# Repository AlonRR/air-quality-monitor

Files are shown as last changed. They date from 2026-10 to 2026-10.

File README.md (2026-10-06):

# Air-quality monitor

An ESPHome air-quality monitor — particles with a Sensirion SPS30, VOC and NOx with a GY-SGP41, on an
ESP32-C3 SuperMini — and the printed box it lives in. It watches the air wherever something puts particles
or gases into it: 3D printing, soldering, laser cutting, resin work, sanding, cooking. Its first job is
beside a 3D printer's enclosure, and that is where the design pages measure it, but nothing in the box
assumes a printer.

The box hangs on a wall by two screws, upright, with the SPS30's air face down. Two parts in ASA,
68.7 × 76.4 × 24 mm: a back plate, and a cover whose top locates on a bump in a U and whose bottom corners
are screwed into nuts, the screws' heads flush in its front.

The SuperMini lies level above the SPS30's lead, held by its edges, its antenna's pole standing up; the
SGP41 lies flat in the column beside the SPS30, close behind vents in the cover's front.

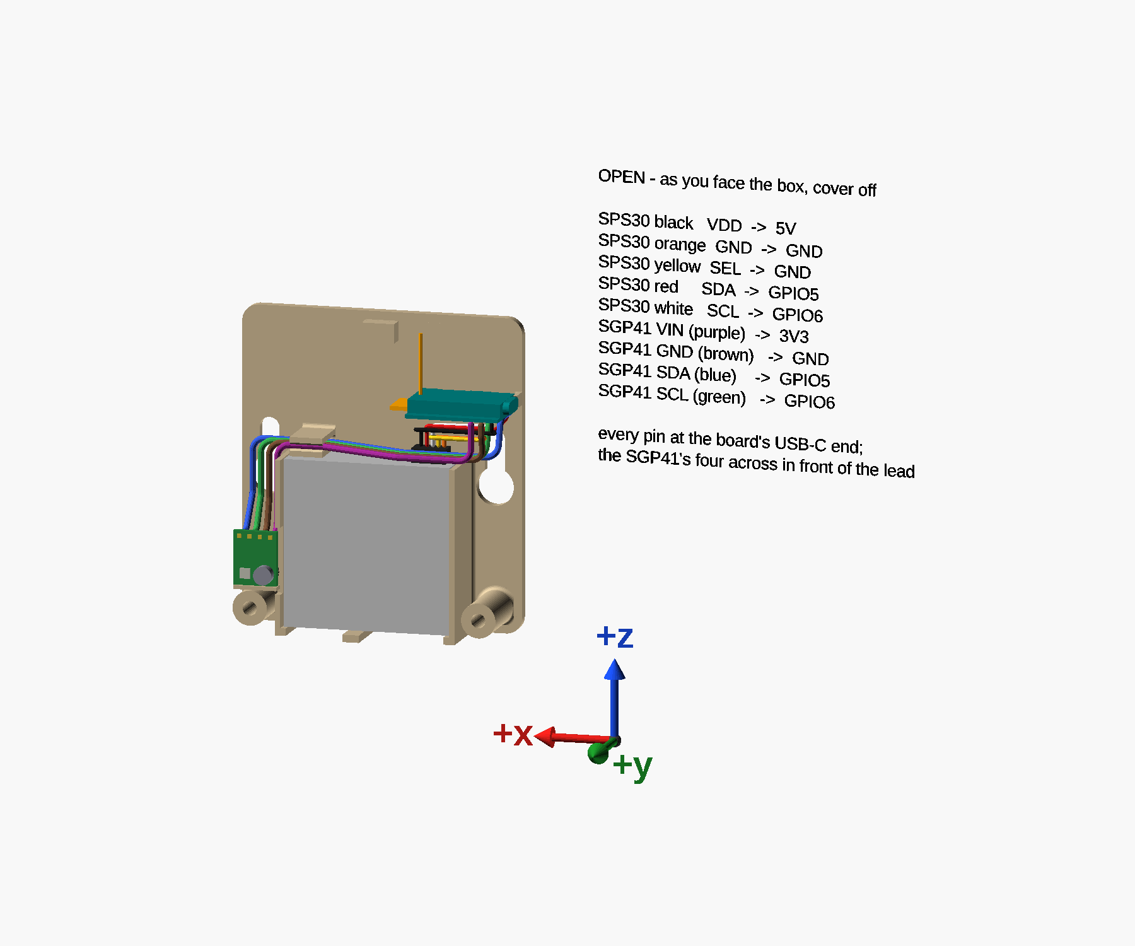
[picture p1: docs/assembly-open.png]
assembled, cover off


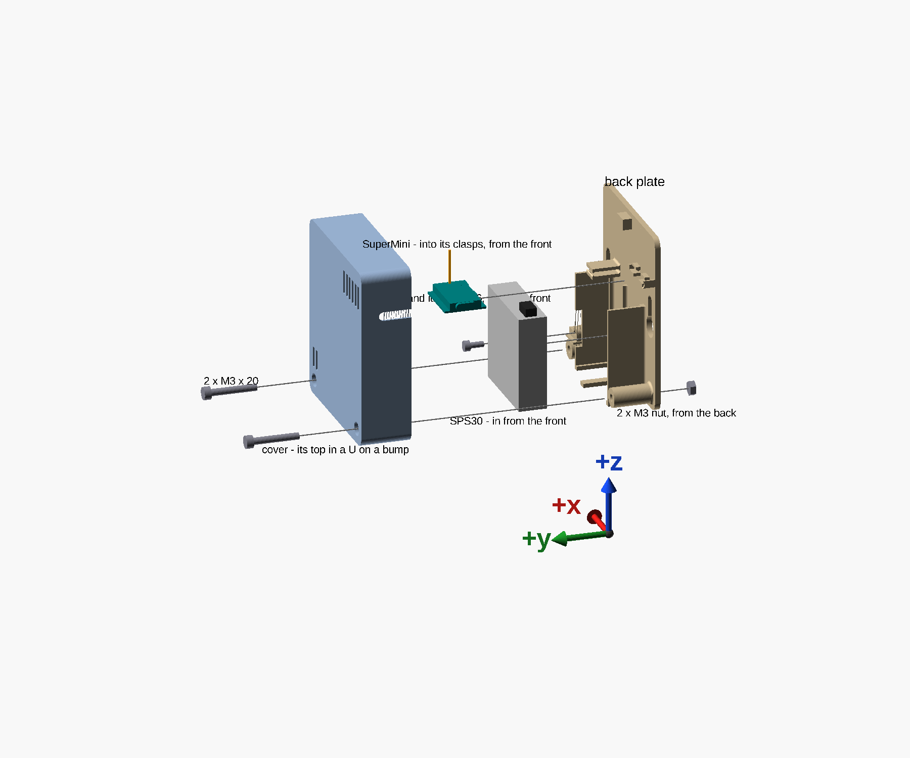
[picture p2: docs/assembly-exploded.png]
every part, moved apart along the way it goes in


Every picture carries the box's own axes as arrows: **x across it, y out from the wall, z up.** Facing the
box, +x points to your left. They are the model's axes, not the printer's: the back plate prints lying on
its back, so on the bed its y is up.

## Status

**The box is modelled, checked, and every fit in it tested** in ASA on the printer; `untested_fits` and
`unmeasured` are both empty, so `scad-check.sh` passes the back plate and the cover.

**Changed since the last printed box** — checked in the model, not printed yet:

- the USB-C slot in the cover's side wall, open to its back edge;
- the divider under the SPS30: a flush wall, placed at the air-face gap measured on the sensor;
- the SGP41 wire channel's lips, now one bead deep;
- the SPS30 standing 2 mm off the plate on three ribs, so air rises behind it and cools it;
- 1 mm fillets at the roots of the thin parts that take a load, and round the SPS30's window.

**The firmware's** configuration is valid and has compiled; it is not flashed yet.

## Building it

1. **Print the two parts** — see *Printing* below.
2. **[Assemble it](docs/assembly.md)**, then **[wire it](docs/wiring.md)**.
3. **Flash the firmware**: copy `firmware/secrets.yaml.example` to `firmware/secrets.yaml`, which is
   gitignored, fill it in, and build [`firmware/print-chamber.yaml`](firmware/print-chamber.yaml) — its
   header says how.

| Part | File | Prints |
|---|---|---|
| Back plate | [`models/air-quality-monitor-back.scad`](models/air-quality-monitor-back.scad) | flat on its back |
| Cover | [`models/air-quality-monitor-cover.scad`](models/air-quality-monitor-cover.scad) | front face down |

**The models need the [`scad-tools`](https://github.com/AlonRR/scad-tools) submodule**, which holds the
shapes they use. Clone with it:

```sh
git clone --recursive https://github.com/AlonRR/air-quality-monitor
```

A ZIP from GitHub comes without it: from the unpacked folder, fetch the version this repository is pinned
to. In PowerShell:

```powershell
$pin = (Invoke-RestMethod https://api.github.com/repos/AlonRR/air-quality-monitor/contents/scad-tools).sha
Invoke-WebRequest "https://github.com/AlonRR/scad-tools/archive/$pin.zip" -OutFile scad-tools.zip
Remove-Item -Recurse -ErrorAction SilentlyContinue scad-tools
Expand-Archive scad-tools.zip . ; Rename-Item "scad-tools-$pin" scad-tools ; Remove-Item scad-tools.zip
```

or in a POSIX shell:

```sh
pin=$(curl -s https://api.github.com/repos/AlonRR/air-quality-monitor/contents/scad-tools | sed -n 's/.*"sha": *"\([0-9a-f]*\)".*/\1/p')
rm -rf scad-tools && mkdir scad-tools && curl -sL "https://github.com/AlonRR/scad-tools/archive/$pin.tar.gz" | tar xz --strip-components=1 -C scad-tools
```

**Hardware:** two M3 × 20 socket head cap screws and two M3 nuts for the cover, one M2.5 × 6 socket head cap
screw for the SGP41, two 4 × 20 chipboard screws and their wall plugs to hang it, and half a metre of
22 AWG solid hookup wire for the SGP41 — [how much each wire takes](docs/wiring.md#how-much-wire). No
tape, no glue.

## Printing

Inslogic ASA, with the print profile **"0.2mm QUALITY @MK3 - no skirt, no brim, no crossing perimeter"**.
No skirt, no brim, no draft shield, and no supports: rounded corners keep ASA's corners down, and every
opening is a hole in the first layers or a notch open at an edge.

## How it is designed

| Page | What it covers |
|---|---|
| [Design](docs/design.md) | the rules the SPS30 sets, the layout they produce, and which way is left |
| [What each feature is for](docs/features.md) | both parts, every feature numbered |
| [The USB-C end](docs/usb-c-end.md) | why any cable fits, and what takes a plug's push and pull |
| [The SGP41's mount](docs/sgp41-mount.md) | how the gas sensor sits close to its vents without loading its parts |
| [Parameters](docs/parameters.md) | every measured, sourced and tested value, and where it came from |
| [Checking it](docs/checking.md) | the checks that guard the design, and the controls that prove each can fail |

## What is where

| | |
|---|---|
| [`docs/`](docs/) | the pages above and their pictures |
| [`models/air-quality-monitor.params.scad`](models/air-quality-monitor.params.scad) | every setting, measurement and fit — the one file to edit |
| [`models/air-quality-monitor.layout.scad`](models/air-quality-monitor.layout.scad) | every dimension the settings imply, and the rules (asserts) they must keep — values only, no geometry |
| [`models/air-quality-monitor.scad`](models/air-quality-monitor.scad) | the model: both parts drawn from the layout, and its collision checks |
| `models/air-quality-monitor-back.scad`, `-cover.scad` | one part each; check and slice through these |
| [`models/assembly-views.scad`](models/assembly-views.scad) | the assembly pictures: exploded; open, with every wire's route and the wiring table; the wires at the pins close up; and the wires' collision check |
| [`models/feature-map.scad`](models/feature-map.scad) | the numbered feature pictures |
| [`models/board-measure.scad`](models/board-measure.scad) | the readings taken on the SuperMini and the GY-SGP41 |
| [`firmware/`](firmware/) | the node's ESPHome configuration, with its wiring table, and the secrets template. It is `print-chamber.yaml`, named for its first job: Home Assistant keys the history it records to that name |
| [`scripts/checks.py`](scripts/checks.py) | the collision checks, the positive controls and the pictures, run as [Checking it](docs/checking.md) describes |
| [`scad-project.toml`](scad-project.toml) | what the shared scripts need to know about this repository: its printed parts |
| [`scad-tools/`](https://github.com/AlonRR/scad-tools) | the shared tools, a git submodule: the xyz arrows, shapes and wire routes the models `use`; `scad-check.sh`; `printables.py`, which makes each printed part one `.scad` and its STL for Printables - `uv run scad-tools/scripts/printables.py`, into `printables/` |

## Licence

This is open hardware. **Commercial use is allowed**, but anyone who ships a product made from these designs
must publish their changes under the same licence.

| Licence | Covers |
|---|---|
| [CERN-OHL-S-2.0](LICENSES/CERN-OHL-S-2.0.txt) — CERN Open Hardware Licence v2, Strongly Reciprocal | the design and its documentation: `models/`, `docs/` and this README |
| [MPL-2.0](LICENSES/MPL-2.0.txt) — Mozilla Public License 2.0 | the code: `firmware/` and `scripts/` |

Every file says which licence applies to it. The `.scad` files, the script and the firmware carry an SPDX
header; `REUSE.toml` covers the rest, and the repository passes `reuse lint`. `LICENSE` at the root is
the CERN-OHL-S text again, for tools that look only there.

## Related

This repository was split out of the [3D-printing toolkit](https://github.com/AlonRR/3d-printing-toolkit),
with its history. The toolkit holds the FDM design rules and the slicer profiles the box is printed with;
the chamber-sensor notes the firmware follows, and the `.yaml` files its comments name, are in
[**printer-enclosure**](https://github.com/AlonRR/printer-enclosure), the enclosure this monitor hangs
beside. A `docs/…` page named in a comment, and not found here, is in one of the two.

_Parts of this repository were drafted with the help of an LLM agent; reviewed and verified locally._

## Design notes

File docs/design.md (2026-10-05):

# Design — why the box looks like this

Most of the layout is decided by the SPS30, and Sensirion publishes the rules. Three more come from
this repository. This page lists them, then shows the layout they add up to.

## The rules

| Rule | Source |
|---|---|
| **Two inlets and one outlet, all on one 40.6 × 12.2 mm face.** The large slotted grille is the **outlet**; the two inlets sit at the other end, one of them wrapping round the edge | *Mechanical Design and Assembly Guidelines for SPS30*, §1 figure |
| **Couple that face to the room through a large opening, with minimal depth in front of it.** A constricted volume in front makes outlet air flow back into the inlets | guidelines §2.1 |
| **A tight seal between the inlet side and the outlet side** gives the best performance | guidelines §2.1 |
| **Openings facing down** is the best orientation — it avoids dust settling in the sensor | guidelines §2.2 |
| **Keep it away from heat sources such as microcontrollers, and below them** — convection from a warm board heats the sensor | guidelines §2.4 |
| **Do not cover the entire sensor surface** in an all-round casing, or it overheats | guidelines §3 |
| **Isolate it from airflow faster than 1 m/s** — so not in the fume fan's stream | guidelines §2.3 |
| **The metal housing is tied to GND and must stay electrically floating**; current through that link *"may damage the product and poses a safety risk through overheating"* | datasheet v2.0 §3 |
| **Connector on the face opposite the openings** | datasheet v2.0 §3 |
| **I2C lead under 20 cm** | datasheet v2.0 §3 |

From this repository:

- **The box sits outside the printer's enclosure.** The SGP41 is rated −10 to +50 °C and the SPS30 to
  +60 °C, against a chamber wanted at 40–60 °C ([chamber-sensor §3](https://github.com/AlonRR/printer-enclosure/blob/main/docs/chamber-sensor/node-design.md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)).
  What those ratings mean is below.
- **A second box inside the chamber is possible, not decided** (Alon, 3 Oct 2026). There are two of
  each sensor, and it would pair with the chamber's air filter — measuring the chamber air out of the
  filter's draught, not built into its air path. Alon does not want to risk the sensors, so it waits
  on more thinking; this box, outside, is built first.
- **The SuperMini carries a 31 mm antenna-wire mod**, whose last 15 mm stand straight up from the
  board ([chamber-sensor §3x](https://github.com/AlonRR/printer-enclosure/blob/main/docs/chamber-sensor/supermini-antenna.md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)). It needs free space in plastic, away
  from the SPS30's grounded metal case.

### Past the ratings

From the datasheets — the SGP41's §2.3–2.4 and the SPS30's (v2.0) §1.2 and §2.2. Neither part stops at
its limit: past it, accuracy goes first, then the part.

| | Performs best | Rated to | Past that |
|---|---|---|---|
| **SGP41** | −10 to 50 °C. Prolonged exposure outside it *"may reduce sensor performance"* | 55 °C, the absolute operating maximum | beyond 55 °C, *"may cause permanent damage"*; long periods at the limits *"may affect sensor performance and reliability"* |
| **SPS30** | 10 to 40 °C | 60 °C, the absolute operating maximum | beyond 60 °C, permanent damage is possible and operation is not guaranteed. The datasheet names a laser failure at very high temperatures, which the sensor flags in its status register. Its precision also drifts by typically 0.5 % of the reading per °C away from 25 °C |

Against the closed chamber — 45–46 °C through an ASA print, 47.5 °C at the peak of a bed anneal
([measurements](https://github.com/AlonRR/printer-enclosure/blob/main/docs/chamber-sensor/measurements.md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)) —
the SPS30 is already above its best range, and the SGP41 is 2.5–5 °C below its 50 °C, before the box's
own heat, which is not measured. Heating the chamber towards 60 °C would take both past their ratings.

## The layout

Every rule points the same way. Stand the SPS30 on edge with its air face **down**, over a window in the
bottom wall; its connector is then **up**, at the outlet end. Lay the SuperMini **level above it**, just
over the lead, so the board's heat rises away from the sensor and its antenna's pole stands up into the
top of the box, away from the sensor's grounded case. Lay the SGP41 flat **beside** the SPS30, its
sensor about 2 mm behind vents in the cover's front.

assembled, cover off

As you face the box, cover off:

- **The SPS30** stands at the bottom centre, in a channel on the back plate, label towards you, its outlet
  on your right. A divider under its air face splits the inlet side from the outlet side.
- **The SuperMini** lies level across your right half, 54.8 mm up, component side up. Its USB-C end is in
  the right-hand wall; its antenna end points to the middle, and the antenna's pole stands 1 mm short of
  the top wall. It is held by its long edges — two clips on the plate take its back edge and a clasp on
  the cover its front edge — so the pins along both stay open from below.
- **The SGP41** lies flat low in the left-hand column, its sensor towards vents in the cover's front and
  its pins up, screwed from the front onto a post rising from the plate.
- **Two keyholes**, one in each side column beside the SPS30's top corners, hang the box on two wall
  screws.
- **The cover** locates at the top on a bump inside a U, and two M3 screws through its bottom corners,
  their heads flush, close it into nuts in the back plate.

**One large window, one divider.** The window is a single opening over the whole air face, split by a
single divider. The box does not have to line up with each grille; it only has to put the divider in
the blank gap between the two ends, which is one number to measure. The divider fills that gap, 4.05 mm
wide and 0.55 mm clear of the openings either side, and ends flush with the box's bottom edge — Sensirion's
own separating wall reaches the device's opening and stops there. It can be no wider: on the inlet side
the gap ends at the slot along the label face's edge, which is the sensor's second inlet.

**The SPS30 stands 2 mm off the plate, for cooling** (`sps_lift`). Three upright ribs hold its back off:
one at each end, against the channel's walls, and one behind the divider. Air comes in through the window
under the sensor, rises up the gap behind it and leaves into the compartment above, past the board and out
through the board's vents. The middle rib splits that gap the way the divider splits the window, so the
outlet's air rising behind the sensor stays on its own side until it is past the sensor's top. The box's depth is set by the
SuperMini's width, not the sensor, so the lift costs only air gap in front of the sensor — 5.6 mm is left,
against `front_gap_min`'s 2.5. What limits it is the sensor's plug, which moves forward with it: the
SGP41's wires pass just in front of the plug, and 2 mm leaves them 0.55 mm clear, where 3 mm ran into them. The SGP41 overhangs only the channel's wall beside it, never the sensor, so
the wall's notch for it may now reach past the sensor's back half: it still guides more than half the
sensor's depth there, and the full depth elsewhere.

**Every pin the node uses is among the first three at the board's USB-C end** — 5V, GND and 3V3 on its
front edge, GPIO5 and GPIO6 on its back edge. So the clips start past the back edge's second pin and the
clasp past the front edge's third, and nothing printed covers a pin that is soldered.

What each feature is for is in [Features](features.md); the SGP41's mount in
[The SGP41's mount](sgp41-mount.md); the USB-C end in [The USB-C end](usb-c-end.md).

## Left and right

**"Left" and "right" always mean as you face the box.** The model's frame is right-handed with Y
pointing out of the wall, so +X is your **left**. The layout above is for the SPS30 in hand, whose outlet
is on your right (`outlet_at_left = false`), so the USB-C cable leaves on your right too.

The model can mirror for a sensor the other way round. A real GY-SGP41 cannot be mirrored, so when the
box is, the model draws the module's mirror image first and it comes out the right way round.

## Printing without support

**The back plate prints on its back.** The keyholes are openings in its first layers. The channel
walls, clips, stop, the SGP41's post, rib and ledge, the bump and the wire channel's ribs are walls
standing on it; the wire channel's lips are 45° ledges at the ribs' tops, and the SGP41's pilot is an
upright hole down its post. The nut pockets open on the bed side, and each pocket's ceiling is bridged in
three layers — a slot the screw hole's width, then a square, then the round hole — so it needs no
support. Nothing overhangs: the SGP41 was first held on edge by a peg standing 2.7 mm sideways out of a
block, and that peg did not print, which is why it now lies flat.

**The cover prints front face down.** The window under the SPS30 is a notch open at the back edge, and
the vents in the front are holes in its first layers. The counterbores the screw heads sit in open on the
bed, and their floors are bridged the same three-layer way as the nut pockets. The partition, baffle,
clasp, stop and U are walls standing on the front. The USB-C slot in the right-hand wall is open at the
cover's back edge — its top on the bed — so it needs no bridge at all.

**No skirt, no brim, no draft shield.** Rounded corners in plan view (`corner_r`) keep ASA's corners
down instead.

## Fillets at the thin parts' roots

**For strength, a concave fillet runs along the root of each thin part**, where it meets the face it stands
on — `fillet_r`, 1 mm, about two beads, so a 0.9–1.35 mm part is roughly twice as thick where it bends.
Only in 90° inside corners; outside edges stay as they are. On the back plate: the SPS30 channel's walls,
the divider, the wire channel's ribs, the USB-C filler, the nut bosses, the back stop and the SGP41's
ledge. On the cover: the partition, the U's arms, the front stop, and all round the inside where the walls
meet the front — the walls already meet each other in a radius.

**Round the window under the SPS30, every corner is filleted, for looks**: the window's two front
corners on the cover, and through it on the plate the divider, the ledges and the standoff ribs where they
meet the plate. The inside cove stops at the window, where there is no bottom wall for the front to meet.

**The board's clips and the cover's clasp have none, on purpose.** They hold the board by flexing, and their
fit was set by printing them; a fillet would stiffen them, change how the board snaps in, and make them
likelier to crack than to give. The baffle, the SGP41's post and rib see almost no load, so they have none
either.

**Some corners stay sharp because something fits against them**, and those are deliberate: the channel
walls' inner faces, which the SPS30 stands 0.355 mm off; the lower wire rib's underside, `part_fit` over the
sensor; the USB-C filler's outside face and its edges in the cover's slot; the divider's top, which carries
the sensor; the stops' faces the board bears on. Each fillet is cut back `fillet_clear` (`part_fit`) from
the cover's walls, the plate's bump and the cover's bottom wall, and the cover's window, thinned USB-C wall
and vents cut through the inside one. [Checking it](checking.md) has the setting that proves those
cut-backs are there.

**No fillet makes an overhang.** The back plate's widen down towards its bed, the cover's towards its front,
which is its bed, and the fillets under the cover's top wall run straight up it.

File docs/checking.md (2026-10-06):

# Checking it

How to tell that the model is still right after a change. There are two layers: the repo's
`scad-check.sh` on each printed part, and five collision checks in the model, backed by its asserts.
The wire routes and their checks are on [Wiring](wiring.md).

Everything below except `scad-check.sh` runs from one script, with OpenSCAD 2021.01 and
[uv](https://docs.astral.sh/uv/), from the repository's root:

```sh
uv run scripts/checks.py collisions   # the five collision checks, the box both ways round; and check_wires
uv run scripts/checks.py controls     # every positive control below and on Wiring, re-measured
uv run scripts/checks.py figures      # every picture in docs/, each render read for errors
uv run scripts/checks.py lengths      # the wire lengths on Wiring, against the routes they come from
```

Each exits 1 if anything is not as this page says. `JOBS=4` runs four renders at once. `figures` renders
into a scratch folder; `figures --write` renders over the pictures in `docs/`. Rendering the same model
twice gives PNGs a few hundred bytes apart, so write and commit them only when the model changed.

Every check here has a **positive control**: a setting that breaks the thing being checked, with what it
measured. A check that has never been seen to fail is not yet evidence. If a control stops failing after
a change, the check has gone blind and needs a new control.

## Each printed part — `scad-check.sh`

Run from the repository's root:

```sh
P="0.2mm QUALITY @MK3 - no skirt, no brim, no crossing perimeter"
scad-tools/scripts/scad-check.sh models/air-quality-monitor-back.scad  "$P" "Inslogic ASA"
scad-tools/scripts/scad-check.sh models/air-quality-monitor-cover.scad "$P" "Inslogic ASA"
scad-tools/scripts/scad-check.sh models/fits/air-quality-monitor-fits.scad  "$P" "Inslogic ASA"
```

Each should report **one manifold part** and `fdm_*` values matching the profile: the back plate and the
cover each 68.7 × 76.3 mm on the bed.

- **Exit 2 is expected** for the back plate and the cover while `untested_fits` or `unmeasured` is not
  empty; exit 0 means both are clear, as they both are now. The clearance test reports neither, so
  it exits 0.
- `scad-check.sh` also fails a G-code with a skirt or a brim. The profile above has neither.
- **Always check through the three wrapper files, never through `air-quality-monitor.scad` itself.** The
  `part` line in the params file is also what you change to look at a part, and `scad-check.sh` takes no
  `-D`, so a check through the model silently checks whichever part is on screen.

## Collisions — in the model

`checks.py collisions` renders each to STL; by hand, from the repository's root:

```sh
openscad -o check.stl -D 'part="check_components"' models/air-quality-monitor.scad
```

**Run each with `outlet_at_left` set both ways** (add `-D outlet_at_left=true`). The model mirrors, and a
check run one way only has passed a mirrored mistake before. `check_parts` touches by design, so CGAL warns
that its zero-volume result is not a valid 2-manifold; that warning is expected there.

| Check | What it intersects | Must be |
|---|---|---|
| `check_parts` | the back plate with the cover | **zero volume** — they meet only where they touch: the cover's back edge on the plate, and the nut bosses' ends on the cover's screw bosses |
| `check_components` | both parts with everything inside: the SPS30; the SuperMini's PCB (less the clips' pinch, which is meant), its parts, USB-C shell, antenna loop and pole; the largest compliant plug's body, seated, with the board pushed against its stops; the column the SPS30's lead rises through; the SGP41 lying flat, less the bare strip and the bare ring round its hole where it bears; its screw's head; and the wall screws' heads behind the plate, all the way from entry to hung | **empty** |
| `check_slide` | the back plate with the SuperMini's way in: each of its pieces swept from in front of the box into its clips | **empty** |
| `check_insert` | the back plate with the SPS30's way in: its outline, nubs included, swept from its seat to the cover's front | **empty** |
| `check_cover_on` | the cover with its way on: everything inside the box — the SPS30, the SuperMini piece by piece, the SGP41 and its screw's head — swept back to the plate, the way each moves against the cover as the cover comes on | **empty** |

"Empty" means OpenSCAD writes no file; "zero volume" means the STL it writes has none.

## Positive controls

Each setting breaks one thing; the check, or an assert, must catch it. Measured 5 Oct 2026.

`checks.py controls` reads both tables from this page, and the wire routes' table from
[Wiring](wiring.md), and runs every row. It fails a control that no longer fails (**blind**: its check can no longer see what it guards) and one that fails by a different
amount than the table gives (**moved**: the geometry changed, so this page is out of date).

| Check | Setting | What it breaks | Measured |
|---|---|---|---|
| `check_parts` | `part_fit = -0.6` | the cover's features overlap the plate's | 237.9 mm³ |
| `check_parts` | `bump_z1 = 75` | the bump at the top into the cover's top wall | 14.4 mm³ |
| `check_parts` | `nut_boss_y1 = 21.5` | the nut bosses run into the cover's screw bosses | 190.5 mm³ |
| `check_components` | `z_f0 = 50` | the board lowered into the column the SPS30's lead rises through | 8.8 mm³ |
| `check_components` | `gy_post_y1 = 18.4` | the SGP41's post pushed up into the module | 6.2 mm³ |
| `check_components` | `gy_standoff_d = 5.6` | the post's top wider than the bare ring round the module's hole | 1.9 mm³ |
| `check_components` | `key_xs = [6.25, 57]` | the left keyhole moved under the SPS30's channel wall: its screw head runs into it | 90.8 mm³ |
| `check_components` | `clip_g_catch = 0.5` | the clips' catch pressing too far into the PCB | 0.61 mm³ |
| `check_components` | `usb_open_r = 1.3` | the USB-C opening's round ends tighter than the shell's | 4.4 mm³ |
| `check_components` | `gy_ch_zc = 44` | the SGP41 wires' channel lowered into the SPS30 | 57.5 mm³ |
| `check_slide` | `stop_x0 = 20` | the stops moved into the board's way in | 3.0 mm³ |
| `check_slide` | `clip_g_mouth = 0.6` | the clips' mouth narrower than the PCB | 0.59 mm³ |
| `check_insert` | `ch_x1 = 50` | the channel's wall moved into the SPS30's way in | 716 mm³ |
| `check_cover_on` | `usb_notch_y0 = 6.5` | the cover's USB-C slot closed behind the socket again, as the first printed cover was | 11.5 mm³ |
| `check_parts` | `usb_fill_h = 2.0` | the back plate's filler taller than the slot it stands in | 1.4 mm³ |
| `check_parts` | `fillet_clear = -0.5` | the fillets no longer cut back from the cover's walls, the plate's bump and the cover's bottom wall | 0.66 mm³ |

These fire an **assert** instead, which stops the render with an `ERROR: Assertion` line:

| Setting | What it breaks |
|---|---|
| `gy_yf = 19.8` | the SGP41's screw head reaches the cover's front |
| `gy_screw_l = 18` | the SGP41's pilot runs out of its post into the plate |
| `ch_notch = 16.6` | the SPS30 channel's wall left whole, within a gap of the SGP41's underside parts |
| `divider_from_inlet_end = 19.3` | the divider's middle moved so near the outlet grille that the gap leaves it less than 3 beads |
| `key_z1 = 25` | the keyholes run into the nut bosses below and the board's clips above |
| `key_shank_d = 5.5` | the keyholes' slots leave the wall screws' heads less than 1 mm to bear on each side |
| `cover_screw_l = 25` | an M3 × 25 through the cover's corner pokes out of the back plate |
| `cb_depth = 2.8` | the cover's screw heads stand proud of its front |
| `clasp_pinch = 0.6` | the clips' catch closes up |
| `clasp_len = 12` | the two back clips run into each other |
| `clip_reach = 3.0` | the clips reach further onto the board than `clip_room` allows |
| `bump_w = 30` | the U at the top reaches the antenna's pole |

**OpenSCAD exits 0 on a failed assert when it writes a picture or an `.echo` file**, and an `.echo`
export puts the `ERROR` line inside the file. Read the output, or render to STL, which does exit 1.

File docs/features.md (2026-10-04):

# What each feature is for

Drawn by [`feature-map.scad`](../models/feature-map.scad), which includes the model, so the numbers move with it.

## The back plate

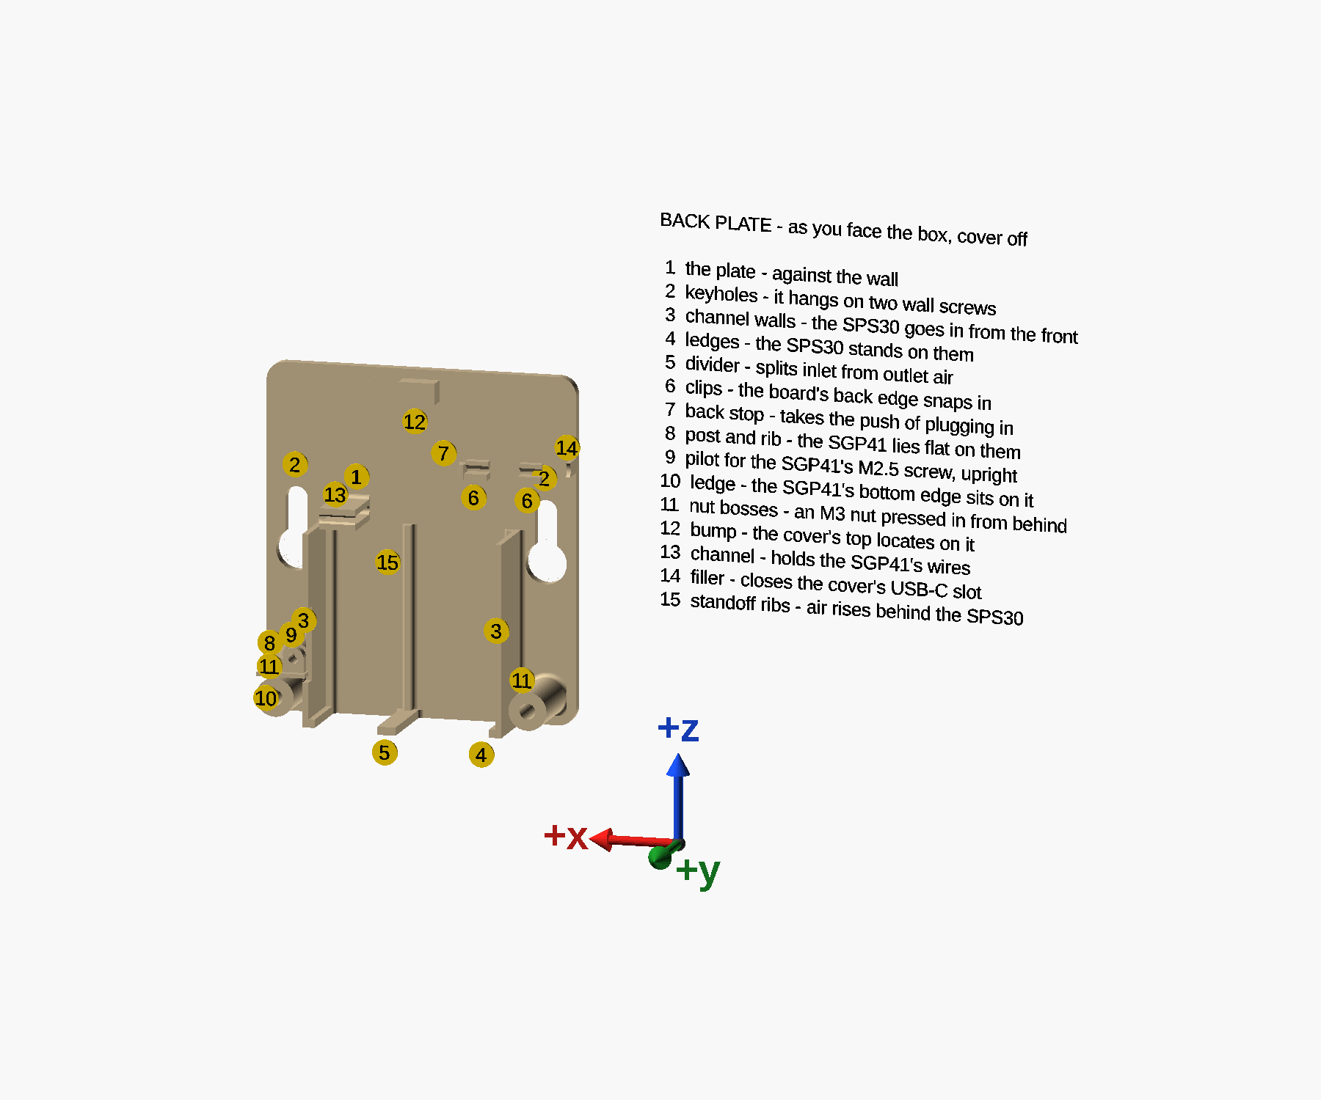
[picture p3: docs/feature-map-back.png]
the back plate, numbered


As you face the box with the cover off:

1. **The plate** — the back of the box, flat against the wall. Everything else stands on it, and it
   prints flat on the bed.
2. **Keyholes** — the box hangs on two wall screws, like a wall clock: each head goes in through a round
   entry, and the box drops so the screws ride up the slots above, their heads behind the plate. One sits
   in each side column, beside the SPS30's top corners. Each slot is 2 mm longer than it needs to be, so
   one screw may sit that much lower than the other. Holes through the plate, so they print as openings
   in the first layers.
3. **Channel walls** — the SPS30 is set between them from the front, and they hold it sideways. They
   have no lips: anything over the sensor's face would block its way in.
4. **Ledges** — the sensor stands on these, one under each end of its air face, clear of the openings.
   They reach out as far as the channel's walls, and the end standoff ribs (15) above them reach in exactly
   as far, so each end is one face.
5. **Divider** — carries the middle of the sensor and splits its inlet side from its outlet side, so
   the outlet's air cannot loop straight back into the inlets. A wall filling the blank band between
   them, `divider_clear` short of each, it ends flush with the box's bottom edge.
6. **Clips** — two, on the SuperMini's back edge: a lower jaw under the edge, and an upper jaw over its
   pad row whose underside angles in to a catch that pinches the PCB, then out again where the edge sits.
   The board's back edge is pushed into them from the front. One is just past the edge's second pin,
   leaving GPIO5 and GPIO6 open; the other is at the antenna end. They reach 2.1 mm onto the board.
7. **Back stop** — over the back corner of the board's antenna end. It takes the push of plugging the
   USB-C cable in; the middle of that end stays open for the antenna loop.
8. **Post and rib** — the SGP41 lies flat on them. The post rises from the plate to the module's
   mounting hole, 6 mm across and narrowing to 4.6 mm where the module's underside parts are, so it bears
   only on the bare ring round the hole. The rib bears on the bare strip along the module's bottom edge.
   The SPS30 channel's wall beside them is notched where the module reaches past its front end.
9. **Pilot** — for the M2.5 × 6 screw, upright down the post: the screw goes in from the front, through
   the module's hole.
10. **Ledge** — the SGP41's bottom edge sits on it, over the nut boss.
11. **Nut bosses** — one in each bottom corner. An M3 nut goes into each hex pocket from the wall side
    and is drawn up to its shoulder by the cover's screw.
12. **Bump** — at the middle of the top. The cover's U straddles it, which locates the cover's top.
13. **Wire channel** — over the SPS30's top-left corner: a slot between two ribs standing on the plate,
    open to the front. The SGP41's four wires press in past a 45° lip, one bead deep, on each rib and lie side by side
    in it, where they turn out of the module's column over the sensor.
14. **USB-C filler** — stands in the cover's USB-C slot behind the socket, and closes the wall there once
    the cover is on. Its end is hollowed round the socket's.
15. **Standoff ribs** — three upright ribs the SPS30 stands on, 2 mm off the plate, so air rises behind it
    from the window and cools it: one at each end of its back, against the channel's walls, and one behind
    the divider, which keeps the outlet's side of that gap apart from the inlets'.

The channel walls (3), divider (5), back stop (7), the SGP41's ledge (10), nut bosses (11), wire channel
(13) and filler (14) have a 1 mm fillet at their roots, for strength — see [Design](design.md#fillets-at-the-thin-parts-roots).

More on 8–10 in [The SGP41's mount](sgp41-mount.md), and on 6 and 7 in [The USB-C end](usb-c-end.md).

## The cover

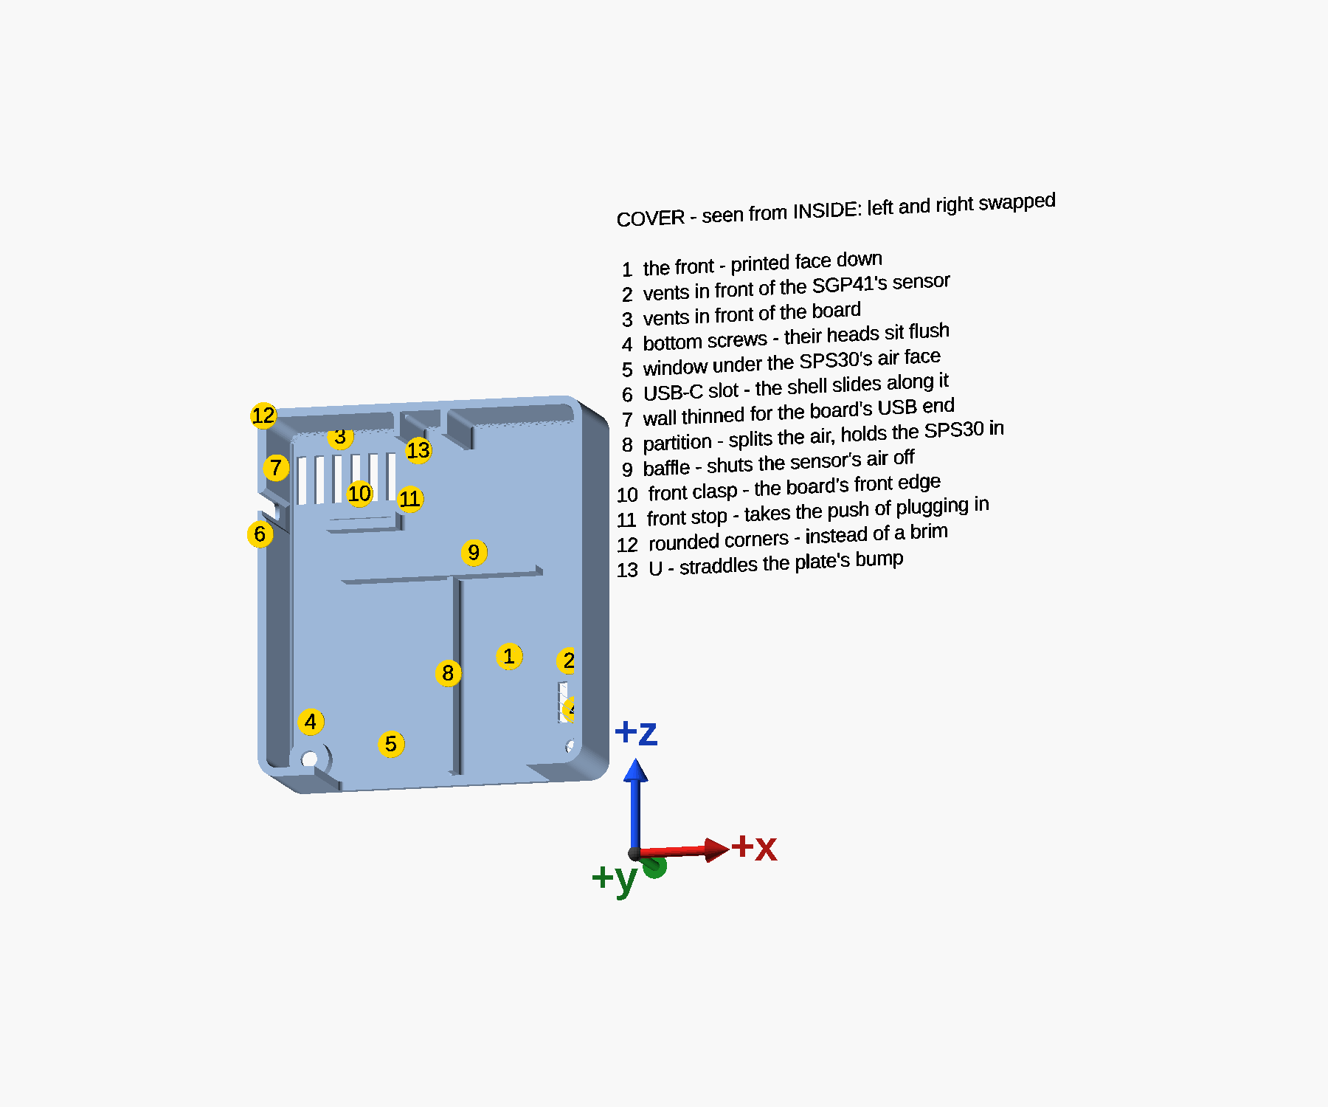
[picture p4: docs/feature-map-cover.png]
the cover from inside, numbered


Seen from inside — from the wall — so its left and right are swapped against the box as you face it:

1. **The front** — printed face down, so it comes out flat.
2. **Vents in front of the SGP41** — room air reaches its sensor, about 2 mm behind them.
3. **Vents in front of the board** — the board's warmth leaves here. With the SGP41's vents lower down
   they should act as a small chimney, drawing fresh air in past the SGP41 (reasoned, not measured).
4. **Bottom screws** — the two M3 × 20 screws' heads sit flush, each in a counterbore 6.0 mm across and
   3.0 mm deep. The front is only 1.8 mm thick, so a boss on its inside carries the floor the head
   clamps on, and the back plate's nut boss meets that boss.
5. **Window** — most of the bottom wall is open under the SPS30's air face, so its inlets and outlet
   breathe the room directly. Open at the back edge, so it prints without a bridge.
6. **USB-C slot** — the socket's metal shell's size and round front end, running on out to the cover's
   back edge, so the cover slides on past the socket; the back plate's filler closes it behind. The
   socket's mouth reaches the outside face, so any cable seats fully.
7. **Thinned wall** — 0.9 mm over the board's USB-C end, so the board reaches into it and the socket
   reaches the outside. The board's corners bear on it when a plug is pulled; its 45° steps keep a crack
   from starting.
8. **Partition** — continues the divider up the air gap in front of the sensor, so the inlet air and the
   outlet air stay apart. It stands 0.2 mm off the sensor's face, so it also keeps the SPS30 from tipping
   forward.
9. **Baffle** — closes that air gap off from the compartment above, so the board's warmth does not drift
   down into the sensor's air.
10. **Front clasp** — takes the board's front edge from its 4th pin to its antenna end: a rim in front of
    the edge, a lip 0.9 mm over its pad strip and a ledge under it. The edge slips in as the cover goes on.
11. **Front stop** — over the front corner of the board's antenna end, the back stop's twin.
12. **Rounded corners** — ASA lifts at sharp corners; the radius is what lets both parts print without a
    brim.
13. **U** — two arms hanging from the top wall, either side of the plate's bump. They locate the cover's
    top; the two bottom screws hold the cover on.

The partition (8), the front stop (11), the U's arms (13), and the walls all round where they meet the
front have a 1 mm fillet at their roots, for strength.

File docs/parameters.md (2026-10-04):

# Parameters

Every dimension has a name in [`air-quality-monitor.params.scad`](../models/air-quality-monitor.params.scad), so a
value goes in against its name rather than a description. This page says where each came from.

If a part changes, set the new value there. A value not yet measured goes in the `unmeasured` list,
and the model warns until it is. The list is empty now.

## Sourced

From the **SPS30 datasheet v2.0**, Figure 7:

| Name | Value | Note |
|---|---|---|
| `sps_h` | **40.6 ± 0.3** | without the shipping foil, which can stay on. The datasheet gives the same for `sps_w`, and 41.2 across the side nubs; both were measured instead, below |
| `sps_t` | **12.2 ± 0.3** | |
| `sps_inlet_end` | **15.22** | where the inlets end, from the inlet end — the slot along the label face's edge reaches furthest. Measured with calipers: it starts 5.20 from the end and is 10.02 long. The datasheet gives 5.2 + 10 |

From the **USB Type-C specification**, rev 1.2, so that no cable needs measuring:

| Name | Value | Note |
|---|---|---|
| `usb_shell_w` | **8.94** | the receptacle's inside opening is 8.34 × 2.56; the measured 3.16 height against 2.56 gives a 0.30 mm shell wall, so 8.34 + 2 × 0.30 |
| `usb_plug_w`, `usb_plug_h` | **12.35 × 6.5** | the largest a compliant plug's body may be (Figure B-1, dimensions 1 and 14). The body stays outside the box, so these only check that it clears the mounting surface |

From **ISO 4762**, the largest socket heads allowed: the SGP41's M2.5 × 6, `gy_head_d` **4.5** and
`gy_head_h` **2.5**; and the cover's M3 × 20, `cover_head_d` **5.5** and `cover_head_h` **3.0**, which
size the counterbores its heads sit flush in.

From **ISO 4032**, the M3 nut: `nut_af` **5.5** across its flats and `nut_h` **2.4** tall, the largest
allowed. The hex pockets are sized from them, and the cover's screw is long enough to pass right through.

## The wall screws

The two 4 × 20 chipboard screws the box hangs on, measured 3 Oct 2026. They size the keyholes: the entry
is the head plus 1 mm (9.2 mm as cut), the slot the thread plus 0.6 mm (4.9 mm as cut), and an assert
keeps at least 1 mm of plate under the head on each side. The first clearance test's G row agrees on the
thread: of 3.8, 4.0 and 4.2 mm holes, the screw fits the 4.2.

| Name | Value | What |
|---|---|---|
| `key_shank_d` | **4.0** | the thread, across |
| `key_head_d` | **7.9** | the head, across |
| `key_head_h` | **2.68** | the head, tall. A chipboard screw's head is usually countersunk; the room behind the plate is drawn as a cylinder the head's full size, which holds for either shape |

## Measured

With calipers on the parts in hand, 2 Oct 2026 unless dated. Three were read off photos first and
measured on 3 Oct 2026 — A, B and C here:

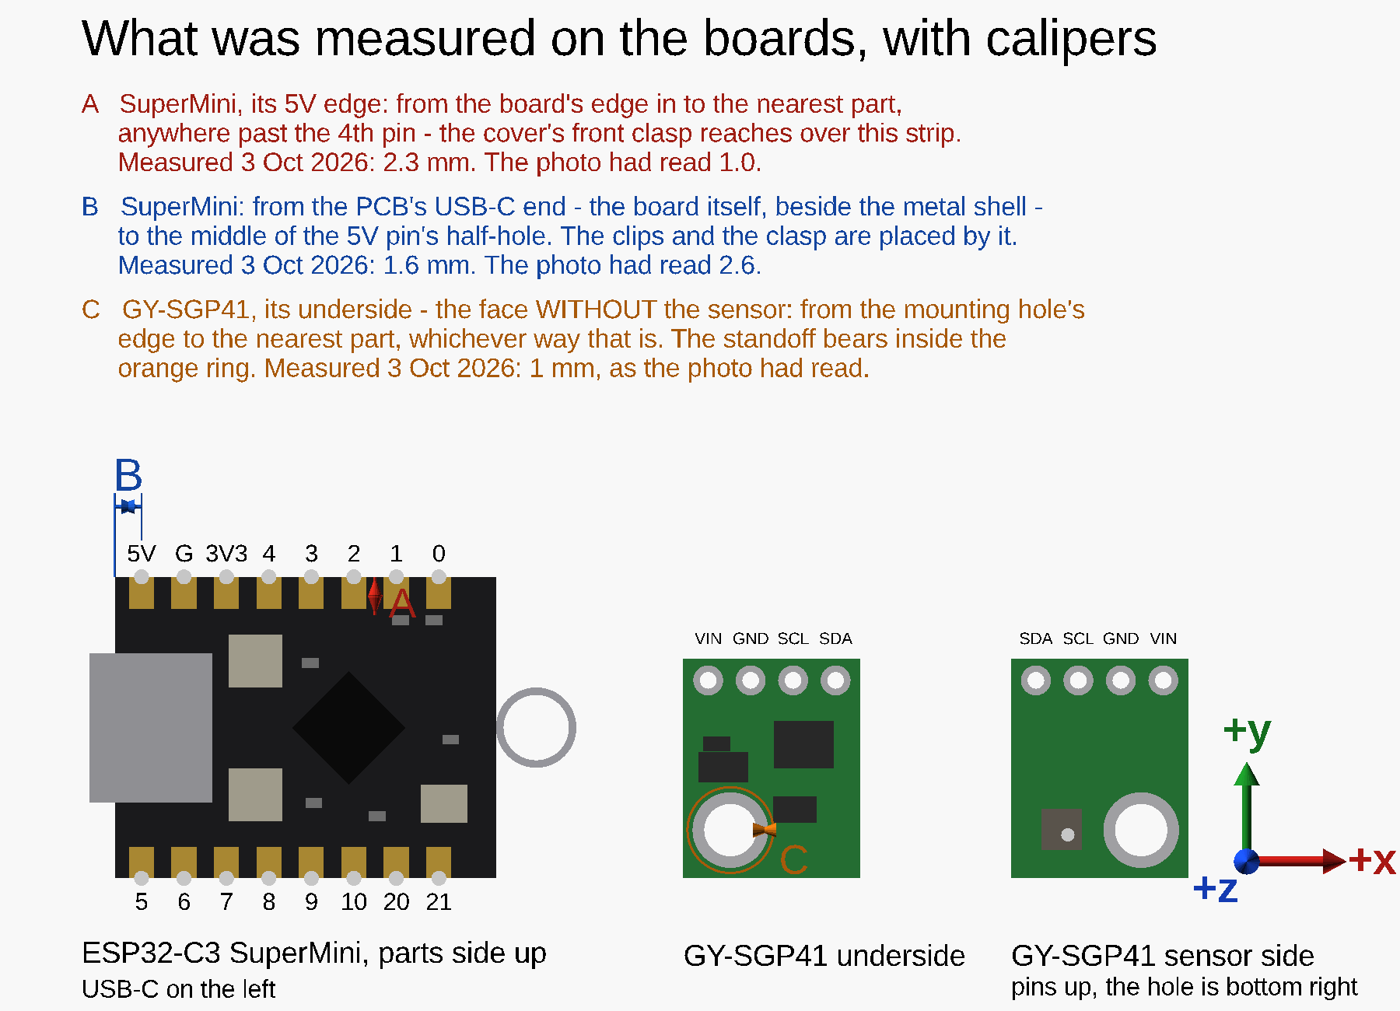
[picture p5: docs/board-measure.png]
the three readings taken on the boards


Drawn by [`board-measure.scad`](../models/board-measure.scad), the boards as they lie on the table.

| Name | Value | What |
|---|---|---|
| `sps_w` | **40.69** | across the SPS30's body, beside its side nubs — measured 3 Oct 2026, reading B in [the figure](sps30-measure.png) |
| `sps_nub` | **0.155** | each side: 41.00 across the nubs (reading A), less the body, halved. The datasheet's 41.2 left the first clearance test's frame A about 0.7 mm loose |
| `divider_from_inlet_end` | **17.8** | from the SPS30's inlet end to the middle of the blank gap before the outlet grille: halfway between `sps_inlet_end` 15.22 and `sps_outlet_from` 20.38. The divider fills the gap round this middle |
| `sm_l`, `sm_w` | **22.8 × 18.03** | the SuperMini's PCB, not counting the USB-C shell |
| `sm_pcb_t`, `sm_t` | **0.85**, **4.05** | the bare PCB; the PCB with its tallest part, the USB-C shell, without the antenna |
| `usb_shell_h`, `usb_overhang` | **3.16**, **1.5** | the USB-C shell's height, and how far it overhangs the PCB's edge |
| `ant_h`, `ant_over` | **18.8**, **4.81** | the antenna wire's tip above the PCB's underside; how far its loop reaches past the PCB's antenna end, in the board's plane |
| `ant_loop_free` | **4.3** | how much of the antenna end the loop leaves free beside it — 4.3 mm one side, 5.45 the other; the smaller is used both sides |
| `sm_edge` | **2.3** | the strip along each long edge of the SuperMini's component side that carries only its castellated pads: from the board's edge to the nearest part. Reading A, on the 5V edge past the 4th pin; the photo had read 1.0. The back edge was not measured — only the clips reach over it, and they keep within `clip_room`. The cover's front lip reaches 0.9 mm over it |
| `pin_mid` | **1.6 + 2.54** | the middle of the SuperMini's three power pins, from its PCB's USB-C end — the board, not the shell that overhangs it. Reading B puts the 5V pin's middle 1.6 mm from that end; the photo had read 2.6, because the shell hides the board's end. The clips and the front clasp are placed from it |
| `cable_zone_h` | **10** | above the SPS30's connector face, with the lead plugged in and bent over as tightly as it comfortably goes |
| `conn_from`, `conn_to` | **2.0**, **10.5** | where the SPS30's plug and lead sit along its top face, from the outlet end: the wires leave 3.0–8.6 mm from that end, and the housing reaches about 1 mm past each |
| `gy_l`, `gy_w`, `gy_t` | **13.14 × 10.60 × 3.24** | the GY-SGP41 with its parts. The sensor is on one face and the rest of its electronics on the other |
| `gy_back` | **2.53** | the GY-SGP41 through its PCB and electronics, clamped beside the sensor: its height lying sensor-up |
| `gy_bare` | **3.31** | from the GY-SGP41's far end (opposite its pins) to the nearest part on its underside |
| `gy_hole_bare_d` | **3.13 + 2 × 1.0** | the bare patch round the mounting hole on the underside: reading C, 1.0 mm from the hole's edge to the nearest part, as the photo had read. The post's 4.6 mm top bears inside it, and the collision check treats its edge as where the parts begin |
| `gy_hole_d` | **3.13** | the GY-SGP41's mounting hole, across |
| `gy_hole_far`, `gy_hole_side` | **1.32**, **1.25** + half the hole | from the hole's edge to the module's far end, and to the nearer long edge (the one away from the sensor). The file adds half the diameter to put the centre at 2.885 and 2.815 |
| `gy_pcb_t` | **1.5** | the GY-SGP41's bare board, measured 3 Oct 2026. With `gy_back` it puts the underside's parts 1.03 mm deep |
| `gy_hole_right` | **true** | which way round the module is: seen from its sensor side with its pins up, the hole is at the bottom right and the sensor at the bottom left — the GY-SGP41 in [the figure](board-measure.png). Read off photo 2, then confirmed on both modules in hand, 3 Oct 2026. Lying flat with its sensor towards the cover and its pins up, the module's hole is therefore at its edge towards the SPS30 |

## Settled from photos

Which way round the parts go, read off photos and checked against the parts:

| Name | Value | What |
|---|---|---|
| `outlet_at_left` | **false** | facing the box, label towards you, air face down, the SPS30's outlet grille is on your right and its two inlets on your left. The connector is at the outlet end |
| `sps_outlet_from` | **20.38** | where the outlet grille starts, from the inlet end. Measured with calipers; the datasheet's 20.2 is 0.18 short. The divider sits between this and `sps_inlet_end` |
| `wire_perpendicular` | **true** | the antenna's straight part, the pole, stands out of the SuperMini's component side, so with the board level it stands up |

## Fits

Clearances that depend on the printer and the filament, found with [the clearance test](clearance-test.md):

| Name | Value | Status |
|---|---|---|
| `sps_fit` | **0.2** | tested 2 Oct 2026, snug — clearance per side round the SPS30. Flush across its thickness, about 0.7 mm loose along its width, until the width was measured (`sps_w`, `sps_nub` above) |
| `pocket_fit` | **0.2** | tested 2 Oct 2026, snug — clearance per side round both boards |
| `part_fit` | **0.3** | tested 3 Oct 2026, 0.26–0.29 per side as printed — between a back-plate feature and the cover |
| `gy_pilot_d` | **2.0** | tested 4 Oct 2026, the third clearance test's M, 1 dot — pilot for the SGP41's M2.5 screw, upright in the flat mount's post. Tried upright in a 6 mm boss on 3 Oct, fine at 2.1, and sideways the same day by the second test's K, whose standoffs did not print |
| `nut_fit` | **0** | tested 3 Oct 2026, the clearance test's J, 2 dots — the M3 nuts' hex pockets, per side on top of the hole compensation: a press fit |
| `clasp_pinch` | **0.1** | tested 3 Oct 2026, the clearance test's L, 2 dots — how much the SuperMini's back clips pinch its PCB at their catch |
| `screw_d` | **3.2** | tested 3 Oct 2026, passes an M3 freely — clearance hole for the M3 screws in the cover |

Every fit is tested, so `untested_fits` is empty and `scad-check.sh` passes; a fit added later goes in it
untested, and the check exits 2 until it is cleared.
Two the first round tested have gone from the box: `pilot_d` with the self-tapping cover screws, and
`tab_hole_d` with the mounting tabs.

## Chosen

Not measured and not tested: sizes the design picks. Widths are whole beads of `fdm_extrusion_w` and
thicknesses whole layers of `fdm_layer_h`, and the model asserts both.

| Name | Value | What |
|---|---|---|
| `wall`, `back_t`, `front_t` | **1.8**, **2.4**, **1.8** | the cover's side, top and bottom walls (4 beads); the back plate (12 layers), which the wall screws' heads bear on; the cover's front (9 layers) |
| `cradle_t`, `rib_t` | **1.35** | the SPS30 channel's walls, and the cover's ribs and the clips' lower jaws: 3 beads |
| `fillet_r` | **1.0** | the concave fillet at each thin part's root, where it meets the face it stands on: about 2 beads, so a 0.9–1.35 mm part is roughly twice as thick where it bends. See [Design](design.md#fillets-at-the-thin-parts-roots) |
| `rim_t`, `port_wall` | **0.9** | rims, jaws and stops: 2 beads. `port_wall` is the cover's wall thinned over the board's USB-C end, as thick as the shell's 1.5 mm overhang allows |
| `ledge` | **1.0** | how far the ledges reach under each end of the SPS30's air face, clear of its openings |
| `divider_clear` | **0.5** | the least room between the divider and the openings either side of it. The divider is derived: the gap round `divider_from_inlet_end`, less this each side, in whole beads — 4.05 mm, 0.555 clear of each. It covers the sensor's tolerance on where its openings are, and its float in the channel |
| `divider_proud` | **0** | how far the divider stands below the box: 0 ends it flush with the bottom edge, where Sensirion's guide ends its separating wall |
| `sps_lift` | **2.0** | how far the SPS30 stands off the plate, on its three ribs, so air rises behind it. The box's depth is set by the board, so this costs only air gap in front of the sensor. Its plug moves forward with it, towards the SGP41's wires in front of it: 2.0 leaves them 0.55 mm clear, 3.0 ran into them |
| `front_gap_min` | **2.5** | the least air gap in front of the SPS30's label face — one inlet wraps round onto it |
| `vent_w`, `vent_rib` | **2.0**, **1.8** | each vent slot, and the material between two |
| `sm_lip_over` | **0.9** | how far the front clasp's lip reaches over the board's front pad strip; an assert keeps it under `sm_edge` |
| `clip_room` | **2.1** | how far from the plate the back clips may reach over the board's pad row. Alon's figure, not measured; the parts envelope keeps out of it only where the clips are |
| `clasp_len`, `clasp_low` | **5.0**, **3.0** | each back clip's length along the edge, and how far its lower jaw reaches under the board |
| `stop_reach` | **3.0** | how far each stop at the antenna end reaches in from a long edge; the loop leaves 4.3 free |
| `gy_wd` | **1.56** | the SGP41's wires: the lab's 22 AWG solid hookup wire, UL1007, measured over its insulation 2 Oct 2026. The wire channel's slot is sized from it |
| `gy_ch_len`, `gy_ch_lip_gap` | **8.0**, **1.06** | the wire channel over the SPS30's top-left corner: its length, and the opening between its two lips — narrower than a wire, so each presses in past them and stays. Each lip reaches one bead, 0.45 mm, into the slot |
| `gy_standoff_d`, `gy_post_d`, `gy_screw_l` | **4.6**, **6.0**, **6.0** | the SGP41's post: its top, inside the bare ring round the module's hole and two beads round the pilot; below the depth of the module's underside parts, as wide as the first clearance test's bosses; and its M2.5 screw's length |
| `key_slack`, `key_level_tol` | **1.0**, **2.0** | how much further than the plate's thickness a wall screw's head may stand off the wall; how much lower one screw may sit than the other |
| `back_wire_room` | **3.0** | the room kept under the board's back edge, over the wall screws' heads, for the wires to GPIO5 and GPIO6: two stacked there, the SGP41's 1.56 mm and a lead wire of about 1 mm. The keyholes sit low enough to leave it — see [Wiring](wiring.md) |
| `bump_w`, `bump_out`, `u_drop` | **8.0**, **4.0**, **5.0** | the bump the cover's top locates on: its width, how far it stands out from the plate, and how far the U's arms hang down round it |
| `cover_screw_l` | **20** | the cover's M3 socket head cap screws. The nut's shoulder sits where, from its flush head, the screw passes right through the nut |
| `corner_r`, `gap` | **4.0**, **1.0** | the plan-view corner radius, which keeps ASA's corners down without a brim; the general clearance between internal features |
| `fdm_layer_h`, `fdm_extrusion_w`, `fdm_hole_comp` | **0.2**, **0.45**, **0.15** | the print profile's layer and bead, which `scad-check.sh` cross-checks; and what is added to every hole's radius, which it does not |

## Not in the params file

Where the wires run, and their bend radii, are in [Wiring](wiring.md).

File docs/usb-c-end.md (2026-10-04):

# The USB-C end

**The socket's mouth reaches the box's outside face, so a plug's body never enters the box.** Any cable
fits, and none needs measuring.

## Why the wall is thinned

The socket's shell overhangs the SuperMini's PCB by only 1.5 mm, so a normal 1.8 mm wall would leave the
mouth inside it. Over the board's end the right-hand wall is therefore thinned from inside to `port_wall`
(0.9 mm, two beads) across the board's whole width and height, and the PCB's end reaches into that
recess. The opening through what is left is the size of the shell, not of a plug: round at its front
end like the shell's, `part_fit` clear all round.

**The opening runs on out to the cover's back edge.** The cover goes on straight back onto the plate,
and by then the shell already stands out through where the wall will be — a wall closed behind the
opening runs into it, and the box does not close (found on the first printed box, 4 Oct 2026). So the
opening is a slot the shell's height, open at the cover's back edge, and the shell slides along it as
the cover comes on. A **filler** on the back plate stands in the slot behind the shell, `part_fit` clear
of its sides and of the shell, and closes the wall again. The cover prints front face down, so the
slot's open end is its top on the bed and needs no bridge; the filler is a 2-bead wall on the plate.
`check_cover_on` sweeps everything inside the box back to the plate, the way it moves against the cover
as the cover comes on, and requires that sweep to miss the cover.

The thinned stretch is the one a plug's pull bears on across the layer lines, so its steps back to the
full wall are 45° chamfers rather than square inside corners, where a crack would start.

**Why not just size the opening for a plug?** A plug-sized opening in the cover alone is not enough: the
back plate's edge, which that opening does not reach, would stop a compliant plug body short of seating.
With the mouth at the face, the plug never comes near either part.

## What takes the push and the pull

The board can move a little along its length, and both ends of that travel are stops:

- **Pulling a plug out** draws the board outwards, `part_fit` (0.3 mm), until the PCB's corners, either
  side of the shell, bear on the thinned wall.
- **Pushing a plug in** drives the board inwards, `pocket_fit` (0.2 mm), against **two stops over the
  corners of its antenna end** — one on the back plate, one on the cover. Without them it would slide
  away from the plug, and the mouth would retreat into the wall at the moment it must not. Each reaches
  `stop_reach` (3 mm) in across the board's end from its long edge. The antenna loop lies in the board's plane past that end and leaves
  at least 4.3 mm of it free each side, so the stops clear the loop by 1.3 mm; an assert keeps it that way.

The clips and the front clasp grip the board's edges too, but the stops are what take the push. Pushed
in, the mouth stands 0.1 mm proud of the outside face; pulled out, 0.6 mm. An assert blocks any setting
that would leave it inside the wall.

## The plug beside the box

The plug's body sits beside the box, its centre 11.6 mm from the mounting surface. A compliant body is at
most 12.35 mm wide (USB Type-C specification), so it clears the wall the box hangs on by 5.4 mm. The model
echoes the figure.

There is no cable clamp on the box; how to secure the cable is in [Assembly](assembly.md#hanging-it).

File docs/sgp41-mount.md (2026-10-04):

# The SGP41's mount

The GY-SGP41 is a small module: a 13.1 × 10.6 mm board, 1.5 mm thick, with the gas sensor on one face, its
other parts on the other, and four pins along one short end. Its mount has three jobs: put the sensor close
behind its vents, carry the board without loading its parts, and print without support.

## Where it sits

**Flat in the left-hand column, beside the SPS30, low down**, its sensor towards the cover's front and
2.1 mm behind vents there, its pins up. It sits as far forward as the screw's head in front of it allows,
and as far from the SPS30 as the side wall allows, so that the wire from its pin nearest the SPS30 clears
the channel's wall.

**Which way round is fixed by the module.** Seen from its sensor side with its pins up, its mounting
hole is at the bottom right (`gy_hole_right`). Facing the box, that puts the hole at the module's edge
towards the SPS30, and the sensor at the edge towards the side wall.

**It reaches past the end of the SPS30 channel's wall**, which stops short of the cover. The wall is
notched there, so the parts on the module's underside clear it by a millimetre; an assert holds that gap.

## How it is held

**One M2.5 × 6 socket head screw, from the front**, through its 3.13 mm mounting hole into a post that
rises from the plate, where it cuts its own thread in an upright pilot (`gy_pilot_d`, 2.0 mm), 4.9 mm
deep. Its head sits between the module and the cover, `part_fit` clear of the cover.

**Its parts never bear load.** The module lies on two things: the post's top, 4.6 mm across
(`gy_standoff_d`), inside the bare ring round the hole — 1.0 mm from the hole's edge to the nearest part
(`gy_hole_bare_d`) — and a rib under the bare strip along its bottom edge, which stops short of the
nearest part 3.31 mm in (`gy_bare`). Below the depth of its underside parts the post widens to 6 mm
(`gy_post_d`). Its bottom edge sits on a ledge over the nut boss.

**It prints without support.** The post, the rib and the ledge all stand on the back plate, so on the bed
they are walls and an upright post, and the pilot is an upright hole. The first mount held the module on
edge by a peg standing sideways out of a block; that peg had nothing under it on the bed, and the second
clearance test's three copies of it did not print usably.

The post is narrower round the pilot than the boss the first clearance test tried the pilot in, so the
[clearance test](clearance-test.md)'s third round tried it again in the post itself: 2.0 mm bites
firmly without splitting it.

Its wires to the SuperMini are in [Wiring](wiring.md).

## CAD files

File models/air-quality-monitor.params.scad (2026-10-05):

// SPDX-FileCopyrightText: 2026 Alon A. Rabinowitz
// SPDX-License-Identifier: CERN-OHL-S-2.0
// Open hardware, made available under the CERN Open Hardware Licence v2 - Strongly Reciprocal
// (LICENSES/CERN-OHL-S-2.0.txt), without any express or implied warranty: see the licence for its conditions.

/*
Everything you SET for the air-quality monitor. Render air-quality-monitor.scad, not this file.

The box for the node in firmware/print-chamber.yaml: an SPS30 particle sensor standing on edge with its
air face DOWN, the ESP32-C3 SuperMini held level by its edges just above its lead, the antenna's pole
standing up, and the GY-SGP41 on edge beside the SPS30, its sensor facing the side wall. It hangs on two
wall screws by keyholes beside the SPS30's top corners. Why that layout, with a source for each rule, is
in docs/design.md; where each value came from, in docs/parameters.md.

COORDINATES are the box as INSTALLED: Y out from the mounting surface, Z up, and X - because the
frame is right-handed - pointing to YOUR LEFT as you face the box. "Left" and "right" in the
comments mean as you face it. The board's USB-C end faces the SPS30's connector, so the USB-C cable
leaves at that end - on your RIGHT with the sensor in hand. The model is drawn that way round, and
mirrored whole when outlet_at_left is set.
*/

/* [Which part] */
part = "back";   /* "back", "cover", or "assembly" (preview only - several parts, not printable). */

/* [The SPS30 - from its datasheet v2.0, Figure 7, and its width measured] */
sps_w    = 40.69;  /* Along the air face (X), across the body beside the nubs. Measured 3 Oct 2026 with calipers (Alon; docs/sps30-measure.png, B). The datasheet gives 40.6 +/- 0.3 without the shipping foil, which can stay on. */
sps_h    = 40.6;   /* The other side of the big face (Z). Datasheet; not measured. */
sps_t    = 12.2;   /* Thickness (Y). 12.2 +/- 0.3. */
sps_nub  = 0.155;  /* Each side: the plastic nubs on the side faces. Measured 41.00 across them on 3 Oct 2026 (Alon; docs/sps30-measure.png, A), so (41.00 - 40.69) / 2. The datasheet's 41.2 across left the clearance test's frame A about 0.7 mm loose in X. */

/* [Measured from the parts in hand - `unmeasured` below lists what is still a placeholder] */
divider_from_inlet_end = 17.8;   /* Along the air face, from the INLET end to the middle of the gap between the inlets and the outlet grille: halfway between the two below. */
sps_inlet_end   = 15.22;         /* Where the inlets END, from the inlet end - the slot along the label face's edge reaches furthest. Measured 4 Oct 2026 (Alon, calipers): it starts 5.20 from the end and is 10.02 long. Datasheet Figure 7: 5.2 + 10. */
sps_outlet_from = 20.38;         /* Where the outlet grille STARTS, from the inlet end. Measured 4 Oct 2026 (Alon, calipers); the datasheet's 20.2 was 0.18 short. The divider must sit between these two. */
outlet_at_left = false;          /* SETTLED from photos, 2 Oct 2026: facing the box, label towards you, air face down, the outlet grille is on your RIGHT and the two inlets on your left. The connector is at the outlet end (datasheet Figure 7, and the photos agree). */
sm_l         = 22.8;   /* SuperMini PCB length, not counting the USB-C shell that overhangs it. Measured 2 Oct 2026. */
sm_w         = 18.03;  /* SuperMini width. Measured. */
sm_pcb_t     = 0.85;   /* Bare PCB thickness. Measured. */
sm_t         = 4.05;   /* PCB plus its tallest component - the USB-C shell - without the antenna. Measured. */
usb_shell_h  = 3.16;   /* The USB-C shell's height. Measured. It sits on the component side (0.85 + 3.16 = 4.01, against sm_t 4.05), so its centre is sm_pcb_t + usb_shell_h / 2 above the PCB's underside. */
wire_perpendicular = true;   /* SETTLED from photos, 2 Oct 2026: the straight part - the pole - stands out of the component side, at an angle - the board leans on it when laid face down. The layout needs it: the board lies level so the pole stands up. */
ant_h        = 18.8;   /* Height of the antenna wire's tip above the PCB's UNDERSIDE, board lying flat. Measured 2 Oct 2026 - with the board level, it sets the box's height. */
ant_over     = 4.81;   /* How far the antenna LOOP reaches past the PCB's antenna end. It lies in the board's plane, so the middle of that end of the pocket is left open for it. Measured. */
ant_loop_free = 4.3;   /* How much of the board's antenna end the loop leaves free beside it: 4.3 mm on one side and 5.45 on the other, measured 2 Oct 2026. The smaller is used on both sides, so the box fits the board either way round. */
pin_mid      = 1.6 + 2.54;   /* The middle of the SuperMini's three power pins (5V, GND, 3V3), from its PCB's USB-C end - the board itself, not the shell that overhangs it. Measured 3 Oct 2026: the 5V pin's middle is 1.6 from that end (reading B in docs/board-measure.png), and the pins are 2.54 apart. Photo 1 had read 2.6. The clips and the clasp that hold the board start past its second and fourth pins, clear of every pin the node solders to. */
usb_overhang = 1.5;    /* How far the USB-C shell overhangs the PCB's edge. It passes through the wall, and its mouth reaches the outside face (see port_wall). Measured. */
usb_shell_w  = 8.94;   /* The USB-C shell's width. Not measured, derived: the USB Type-C compliance document fixes the receptacle's inside opening at 8.34 x 2.56 mm, and the measured height 3.16 against that 2.56 gives a 0.30 mm shell wall - so 8.34 + 2 x 0.30. */
gy_l        = 13.14;  /* GY-SGP41 module. Measured 2 Oct 2026. */
gy_w         = 10.60;
gy_t         = 3.24;   /* With its parts. The sensor is on one face and the rest of the electronics on the other: it lies flat with its sensor towards the cover's vents and its electronics towards the plate, raised on a post. */
gy_back      = 2.53;   /* The GY-SGP41 through its PCB and electronics, clamped beside the sensor - its height lying sensor-up on its electronics. Measured 2 Oct 2026. The sensor makes up the rest of gy_t. */
gy_bare      = 3.31;   /* The nearest part on the GY-SGP41's underside, from the end opposite its pins. Measured 2 Oct 2026. Across the module's whole width, so the rib it lies on stops `gap / 2` short of it, and its parts never bear load. */
gy_standoff_d = 4.6;   /* The post's top, where the screw clamps the module onto it: inside the bare patch round the mounting hole (gy_hole_bare_d), and two beads and more round the pilot. */
gy_post_d    = 6.0;    /* The post below that, where the module's underside parts do not reach: as wide as the first clearance test's bosses, which took this screw upright. */
gy_hole_d    = 3.13;   /* The GY-SGP41's mounting hole. Measured 2 Oct 2026. It takes the M2.5 screw that holds the module down. */
gy_hole_bare_d = gy_hole_d + 2 * 1.0;   /* The bare patch round the mounting hole on the underside, where the standoff bears: the nearest part is 1.0 from the hole's edge. Measured 3 Oct 2026 (reading C in docs/board-measure.png), as photo 2 had read it. The collision check uses it as the parts' edge. */
gy_hole_far  = 1.32 + gy_hole_d / 2;   /* The hole's centre from the module's far end, the short edge opposite its pins: 1.32 to the hole's edge, measured 2 Oct 2026. */
gy_hole_side = 1.25 + gy_hole_d / 2;   /* The hole's centre from the nearer long edge, the one away from the sensor: 1.25 to the hole's edge, measured 2 Oct 2026. */
gy_hole_right = true;  /* Which way round the module is: seen from its sensor side with its pins up, the hole is at the bottom RIGHT and the sensor at the bottom left. From photo 2, 2 Oct 2026, and confirmed on both modules in hand on 3 Oct 2026 (Alon). */
conn_from    = 2.0;    /* The SPS30's plug and lead, along its top face, from the OUTLET end. Photo 1, 2 Oct 2026, scaled against the 40.6 mm sensor: the wires leave 3.0 to 8.6 mm from that end, and the plug's housing reaches about 1 mm past each. Nothing stands in that column. */
conn_to      = 10.5;
cable_zone_h = 10.0;   /* Room above the SPS30's connector face: lead plugged in and bent over as tightly as it comfortably goes, from the sensor's top to the highest wire. Measured 2 Oct 2026. */

/* The wall screws the box hangs on, by the two keyholes in its back plate: 4 x 20 chipboard screws,
   measured 3 Oct 2026. A chipboard screw's head is usually countersunk; the room behind the plate is
   drawn as a cylinder the head's full width and height, which holds for either shape. */
key_shank_d = 4.0;    /* Its thread, across. The 2 Oct clearance test's G row agrees: of 3.8, 4.0 and 4.2 mm holes, it fits the 4.2. */
key_head_d  = 7.9;    /* Its head, across. */
key_head_h  = 2.68;   /* Its head, tall. */

unmeasured = [];
/* Delete a name from this list once its value is measured. While any remain, the model echoes a
   WARNING and scad-check.sh exits 2 - which is the INTENDED state until then. */
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

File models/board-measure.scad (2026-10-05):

// SPDX-FileCopyrightText: 2026 Alon A. Rabinowitz
// SPDX-License-Identifier: CERN-OHL-S-2.0
// Open hardware, made available under the CERN Open Hardware Licence v2 - Strongly Reciprocal
// (LICENSES/CERN-OHL-S-2.0.txt), without any express or implied warranty: see the licence for its conditions.

/*
What was measured on the two boards on 3 Oct 2026, replacing three values read off photos: A, the strip of bare pads
along the SuperMini's 5V edge, which the cover's front clasp reaches over (sm_edge); B, where its 5V pin
is (pin_mid, which is two pins further along); C, the bare ring round the GY-SGP41's mounting hole on its
underside, where the standoff bears (gy_hole_bare_d). The GY-SGP41 is drawn from both sides, so the hole
can be matched to the right face.

Drawn as the boards lie on the table, seen from above: x to the right, y up the picture, z towards you.
Outlines and pins are the params file's; the parts on the boards are only roughly where the photos put
them.

`uv run scripts/checks.py figures --write` renders it with the other pictures and reads the output; by hand:

    openscad -o docs/board-measure.png --imgsize=1800,1300 --projection=o \
      --camera=35,22.3,0,0,0,0,152 --colorscheme=Tomorrow models/board-measure.scad
*/
include <air-quality-monitor.params.scad>
use <../scad-tools/lib/axes.scad>
draw_model = false;   // only the variables

cam = [0, 0, 0];      // seen from straight above, so the text needs no turning
pin_pitch = 2.54;
p1 = pin_mid - pin_pitch;            // the 5V pin, from the PCB's USB-C end
C_A = [0.80, 0.15, 0.10];
C_B = [0.10, 0.35, 0.80];
C_C = [0.85, 0.45, 0.05];
top = 6;                              // above every board, so the dimensions are never hidden

module flat(t, p, size = 1.4, col = "black", h = "left") translate(p) color(col)
    linear_extrude(0.1) text(t, size = size, halign = h, valign = "center", font = "Liberation Sans");

// a dimension line from a to b in the picture's plane, with arrowheads at both ends
module dim(a, b, col) {
    v = b - a; l = norm(v); ang = atan2(v[1], v[0]);
    color(col) translate([a[0], a[1], top]) rotate([0, 0, ang]) {
        rotate([0, 90, 0]) cylinder(d = 0.2, h = l, $fn = 8);
        rotate([0, 90, 0]) cylinder(d1 = 0, d2 = 0.9, h = 1.2, $fn = 16);
        translate([l, 0, 0]) rotate([0, -90, 0]) cylinder(d1 = 0, d2 = 0.9, h = 1.2, $fn = 16);
    }
}
// an extension line, from a feature out to its dimension line
module ext(a, b, col) {
    v = b - a;
    color(col) translate([a[0], a[1], top]) rotate([0, 0, atan2(v[1], v[0])]) rotate([0, 90, 0])
        cylinder(d = 0.12, h = norm(v), $fn = 6);
}
module ring(c, r, w, col) color(col) translate([c[0], c[1], top - 0.5])
    difference() { cylinder(r = r + w / 2, h = 0.1, $fn = 72); translate([0, 0, -1]) cylinder(r = r - w / 2, h = 2, $fn = 72); }

// ------------------------------------------------------------------ the SuperMini, parts side up
module supermini() {
    // the PCB, its USB-C shell overhanging the left end, and its antenna loop past the right one
    color([0.13, 0.13, 0.14]) cube([sm_l, sm_w, sm_pcb_t]);
    color([0.72, 0.72, 0.74]) translate([-usb_overhang, sm_w / 2 - usb_shell_w / 2, sm_pcb_t])
        cube([7.35, usb_shell_w, usb_shell_h]);
    color([0.75, 0.75, 0.78]) translate([sm_l + ant_over / 2, sm_w / 2, sm_pcb_t])
        difference() { cylinder(r = ant_over / 2, h = 0.5, $fn = 48); translate([0, 0, -1]) cylinder(r = ant_over / 2 - 0.45, h = 3, $fn = 48); }
    // its castellated pins: a gold pad at each, the half-hole in the edge
    for (i = [0 : 7], e = [0, 1]) let(x = p1 + i * pin_pitch, y = e * sm_w) {
        color([0.85, 0.68, 0.25]) intersection() {
            translate([x - 0.75, e == 0 ? 0 : sm_w - 1.9, sm_pcb_t]) cube([1.5, 1.9, 0.05]);
            cube([sm_l, sm_w, sm_pcb_t + 1]);
        }
        color("white") translate([x, y, sm_pcb_t]) cylinder(d = 0.9, h = 0.1, $fn = 24);
    }
    // its parts, roughly: the chip, the two buttons, the crystal and some small ones
    color([0.05, 0.05, 0.05]) translate([14, sm_w / 2, sm_pcb_t]) rotate([0, 0, 45]) translate([-2.4, -2.4, 0]) cube([4.8, 4.8, 0.9]);
    color([0.80, 0.78, 0.70]) for (y = [3.4, 11.4]) translate([6.8, y, sm_pcb_t]) cube([3.2, 3.2, 1.5]);
    color([0.80, 0.78, 0.70]) translate([18.3, 3.3, sm_pcb_t]) cube([2.8, 2.3, 0.8]);
    color([0.55, 0.55, 0.55]) for (p = [[11.2, 12.6], [16.6, sm_w - sm_edge - 0.6], [18.6, sm_w - sm_edge - 0.6], [19.6, 8.0], [11.4, 4.2], [15.2, 3.4]])
        translate([p[0], p[1], sm_pcb_t]) cube([1.0, 0.6, 0.5]);
    // the pins' names, as the board's labels read
    for (i = [0 : 7]) {
        flat(["5V", "G", "3V3", "4", "3", "2", "1", "0"][i], [p1 + i * pin_pitch, sm_w + 1.4, top], 1.05, "black", "center");
        flat(["5", "6", "7", "8", "9", "10", "20", "21"][i], [p1 + i * pin_pitch, -1.4, top], 1.05, "black", "center");
    }
}
supermini();

// A: from the 5V edge in to the nearest part, past the 4th pin
xa = p1 + 5.5 * pin_pitch;
dim([xa, sm_w], [xa, sm_w - sm_edge], C_A);
flat("A", [xa + 0.8, sm_w - 1.6, top], 1.8, C_A);
// B: from the PCB's USB-C end to the middle of the 5V pin, run above the pin names
yb = sm_w + 4.2;
dim([0, yb], [p1, yb], C_B);
ext([0, sm_w], [0, yb + 0.8], C_B);  ext([p1, sm_w + 2.2], [p1, yb + 0.8], C_B);
flat("B", [p1 / 2, yb + 1.9, top], 2.0, C_B, "center");

// ------------------------------------------------------------------ the GY-SGP41, both sides
gx0 = 34;                            // its underside, beside the SuperMini
gx1 = gx0 + gy_w + 9;                // its sensor side, beside that
hole_s = [gy_w - gy_hole_side, gy_hole_far];   // the hole, seen from the sensor side: bottom right
hole_u = [gy_hole_side, gy_hole_far];          // ... and from the underside, the mirror image
pin_xs = [gy_w / 2 - 3 * 1.27, gy_w / 2 - 1.27, gy_w / 2 + 1.27, gy_w / 2 + 3 * 1.27];

module gy_board(holexy, names) {
    color([0.18, 0.55, 0.25]) difference() {
        cube([gy_w, gy_l, 0.8]);
        translate([holexy[0], holexy[1], -1]) cylinder(d = gy_hole_d, h = 3, $fn = 48);
        for (x = pin_xs) translate([x, gy_l - 1.3, -1]) cylinder(d = 1.0, h = 3, $fn = 24);
    }
    color([0.80, 0.80, 0.82]) translate([holexy[0], holexy[1], 0.8])
        difference() { cylinder(d = gy_hole_d + 1.4, h = 0.05, $fn = 48); translate([0, 0, -1]) cylinder(d = gy_hole_d, h = 3, $fn = 48); }
    color([0.80, 0.80, 0.82]) for (x = pin_xs) translate([x, gy_l - 1.3, 0.8])
        difference() { cylinder(d = 1.8, h = 0.05, $fn = 24); translate([0, 0, -1]) cylinder(d = 1.0, h = 3, $fn = 24); }
    for (i = [0 : 3]) flat(names[i], [pin_xs[i], gy_l + 1.2, top], 0.72, "black", "center");
}

// the underside: the parts round the hole only roughly where photo 2 put them
translate([gx0, 0, 0]) {
    gy_board(hole_u, ["VIN", "GND", "SCL", "SDA"]);
    color([0.20, 0.20, 0.20]) {
        translate([hole_u[0] + gy_hole_bare_d / 2, gy_bare, 0.8]) cube([2.6, 1.6, 0.7]);
        translate([0.9, hole_u[1] + gy_hole_bare_d / 2 + 0.3, 0.8]) cube([3.0, 1.8, 0.7]);
        translate([5.4, 6.6, 0.8]) cube([3.6, 2.8, 1.1]);
        translate([1.2, 7.6, 0.8]) cube([1.6, 0.9, 0.5]);
    }
    ring(hole_u, gy_hole_bare_d / 2, 0.14, C_C);
}
// C: from the hole's edge to the nearest part
dim([gx0 + hole_u[0] + gy_hole_d / 2, hole_u[1]], [gx0 + hole_u[0] + gy_hole_bare_d / 2, hole_u[1]], C_C);
flat("C", [gx0 + 6.6, 1.1, top], 1.8, C_C, "center");

// the sensor side, as photo 2 shows it: the sensor bottom left, the hole bottom right
translate([gx1, 0, 0]) {
    gy_board(hole_s, ["SDA", "SCL", "GND", "VIN"]);
    color([0.45, 0.42, 0.38]) translate([1.8, 1.7, 0.8]) cube([2.44, 2.44, 0.7]);
    color("white") translate([3.4, 2.6, 1.5]) cylinder(d = 0.8, h = 0.1, $fn = 24);
}

// ------------------------------------------------------------------ the words
flat("What was measured on the boards, with calipers", [-2, 50, 0], 2.2);
lines = [
    ["A   SuperMini, its 5V edge: from the board's edge in to the nearest part,", C_A],
    ["     anywhere past the 4th pin - the cover's front clasp reaches over this strip.", C_A],
    [str("     Measured 3 Oct 2026: ", sm_edge, " mm. The photo had read 1.0."), C_A],
    ["B   SuperMini: from the PCB's USB-C end - the board itself, beside the metal shell -", C_B],
    ["     to the middle of the 5V pin's half-hole. The clips and the clasp are placed by it.", C_B],
    [str("     Measured 3 Oct 2026: ", pin_mid - pin_pitch, " mm. The photo had read 2.6."), C_B],
    ["C   GY-SGP41, its underside - the face WITHOUT the sensor: from the mounting hole's", C_C],
    ["     edge to the nearest part, whichever way that is. The standoff bears inside the", C_C],
    [str("     orange ring. Measured 3 Oct 2026: ", (gy_hole_bare_d - gy_hole_d) / 2, " mm, as the photo had read."), C_C]];
for (i = [0 : len(lines) - 1])
    flat(lines[i][0], [-2, 46.2 - i * 1.75 - floor(i / 3) * 0.9, 0], 1.15, lines[i][1]);
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

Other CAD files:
models/print-chamber-box/board-measure.scad
models/print-chamber-box/print-chamber-box.params.scad
models/air-quality-monitor-back.scad
models/air-quality-monitor-cover.scad
models/air-quality-monitor-fits.scad
models/air-quality-monitor.layout.scad
models/air-quality-monitor.scad
models/assembly-views.scad
models/feature-map.scad
models/fits-map.scad
models/fits/air-quality-monitor-fits.scad
models/fits/fits-map.scad
models/fits/sps30-measure.scad
models/print-chamber-box/assembly-views.scad
models/print-chamber-box/feature-map.scad
models/print-chamber-box/fits-map.scad
models/print-chamber-box/print-chamber-box-back.scad
models/print-chamber-box/print-chamber-box-cover.scad
models/print-chamber-box/print-chamber-box-fits.scad
models/print-chamber-box/print-chamber-box.scad
models/print-chamber-box/sps30-measure.scad
models/sps30-measure.scad

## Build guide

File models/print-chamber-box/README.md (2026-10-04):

# print-chamber box

An enclosure for the printer chamber node: an ESP32-C3 SuperMini, a Sensirion SPS30 particle sensor and
a GY-SGP41 VOC/NOx module, running [`firmware/print-chamber.yaml`](../../firmware/print-chamber.yaml). It
hangs on the wall outside the printer's enclosure, upright, with the SPS30's air face down. Two parts in
ASA, 68.7 × 76.4 × 24 mm: a back plate, and a cover whose top locates on a bump in a U and whose bottom
corners are screwed into nuts, the screws' heads flush in its front. It hangs on two wall screws by
keyholes beside the SPS30's top corners.

The SuperMini lies level above the SPS30's lead, held by its edges, its antenna's pole standing up; the
SGP41 lies flat in the column beside the SPS30, close behind vents in the cover's front.

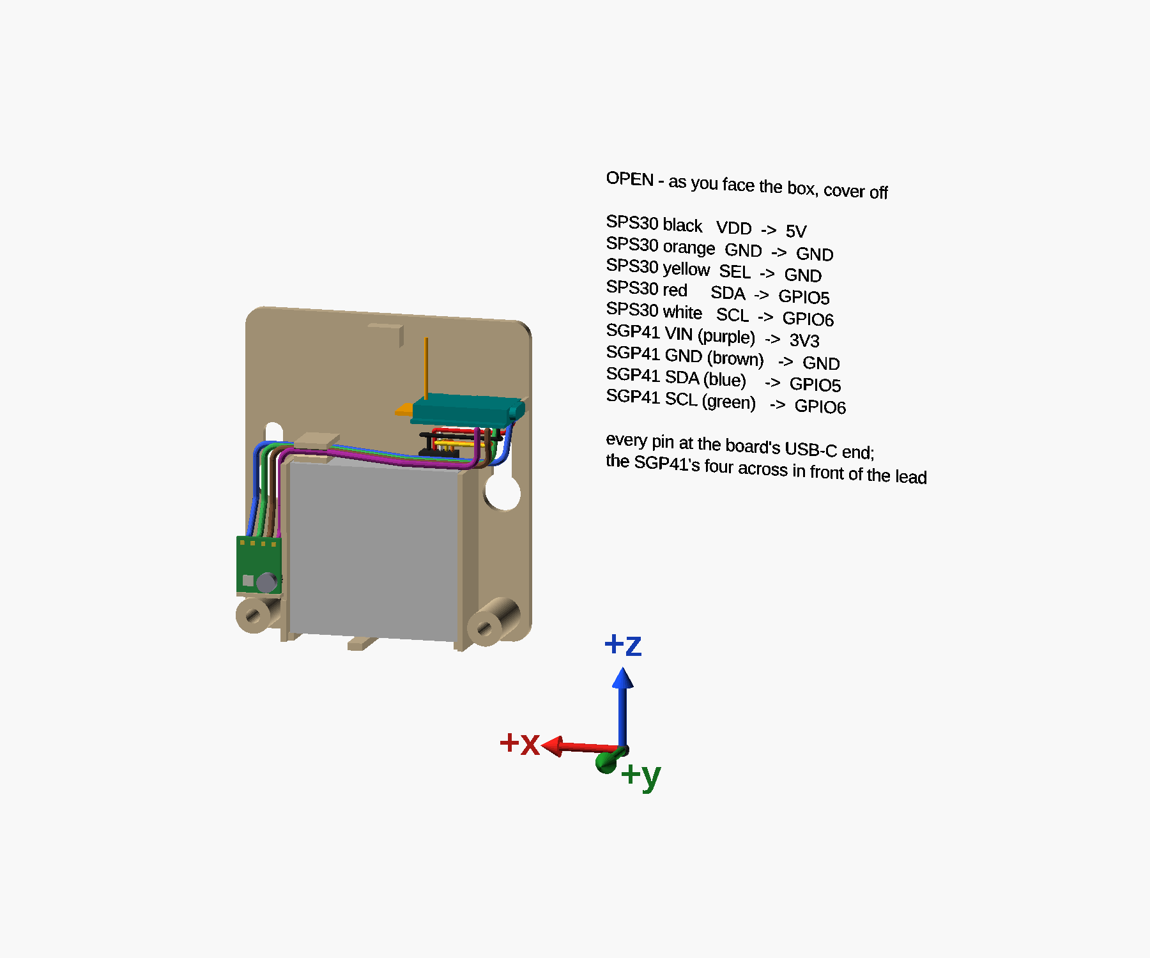
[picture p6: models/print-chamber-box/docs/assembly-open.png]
assembled, cover off


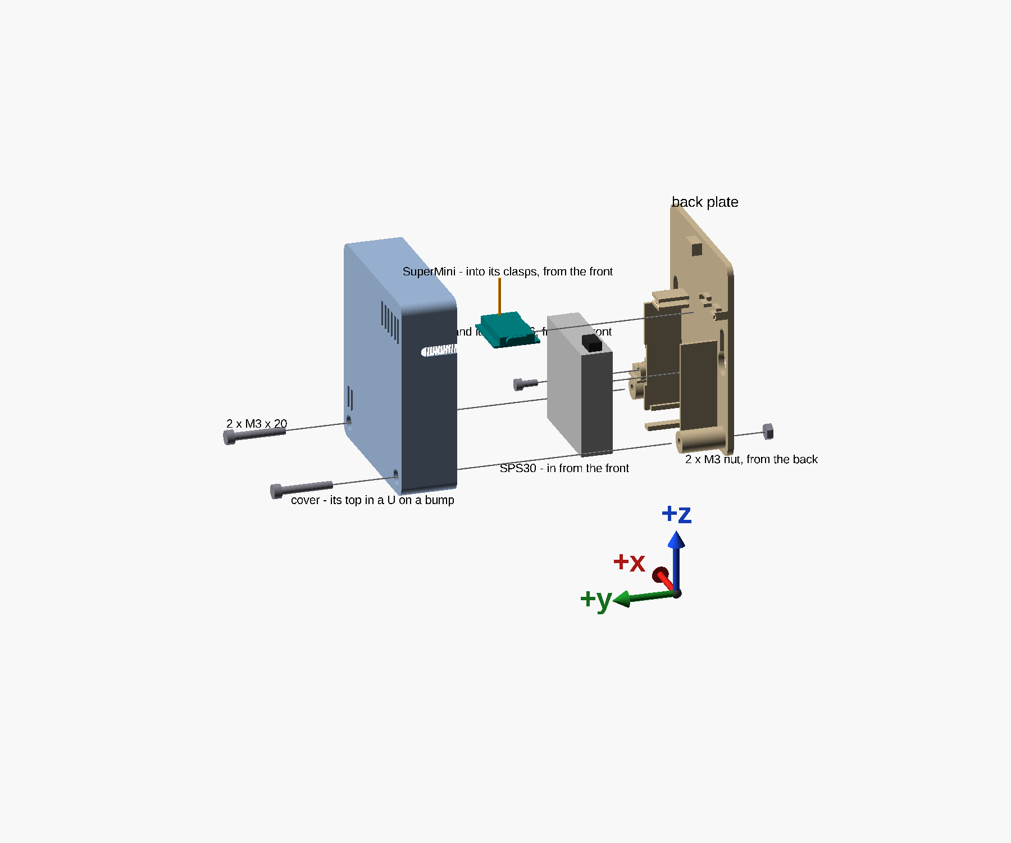
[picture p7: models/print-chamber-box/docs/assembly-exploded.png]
every part, moved apart along the way it goes in


Every picture carries the box's own axes as arrows: **x across it, y out from the wall, z up.** Facing the
box, +x points to your left. They are the model's axes, not the printer's: the back plate prints lying on
its back, so on the bed its y is up.

## Status

**Modelled, checked, and every fit tested — ready to print.** Three rounds of the
[clearance test](docs/clearance-test.md) tried every fit in ASA on this printer, the last on 4 Oct 2026;
`untested_fits` and `unmeasured` are both empty, so `scad-check.sh` passes the back plate and the cover.
The USB-C slot in the cover's side wall and the flush divider under the SPS30 changed after the last
printed box: both are checked in the model, and not printed yet.

## Building it

1. **[Print the clearance test](docs/clearance-test.md)** and set the fits it finds.
2. **Print the two parts** — see *Printing* below.
3. **[Assemble it](docs/assembly.md)**, then **[wire it](docs/wiring.md)**.

| Part | File | Prints |
|---|---|---|
| Back plate | [`print-chamber-box-back.scad`](print-chamber-box-back.scad) | flat on its back |
| Cover | [`print-chamber-box-cover.scad`](print-chamber-box-cover.scad) | front face down |
| Clearance test | [`print-chamber-box-fits.scad`](print-chamber-box-fits.scad) | flat |

**Hardware:** two M3 × 20 socket head cap screws and two M3 nuts for the cover, one M2.5 × 6 socket head cap screw for
the SGP41, two 4 × 20 chipboard screws and their wall plugs to hang it, and 22 AWG solid hookup wire
for the SGP41. No tape, no glue.

## Printing

Inslogic ASA, with the print profile **"0.2mm QUALITY @MK3 - no skirt, no brim, no crossing perimeter"**.
No skirt, no brim, no draft shield, and no supports: rounded corners keep ASA's corners down, and every
opening is a hole in the first layers or a notch open at an edge.

## How it is designed

| Page | What it covers |
|---|---|
| [Design](docs/design.md) | the rules the SPS30 sets, the layout they produce, and which way is left |
| [What each feature is for](docs/features.md) | both parts, every feature numbered |
| [The USB-C end](docs/usb-c-end.md) | why any cable fits, and what takes a plug's push and pull |
| [The SGP41's mount](docs/sgp41-mount.md) | how the gas sensor sits close to its vents without loading its parts |
| [Parameters](docs/parameters.md) | every measured, sourced and tested value, and where it came from |
| [Checking it](docs/checking.md) | the checks that guard the design, and the controls that prove each can fail |

## Files

| File | |
|---|---|
| [`print-chamber-box.params.scad`](print-chamber-box.params.scad) | every setting, measurement and fit — the one file to edit |
| [`print-chamber-box.scad`](print-chamber-box.scad) | the model, its asserts and its collision checks |
| `print-chamber-box-back.scad`, `-cover.scad`, `-fits.scad` | one part each; check and slice through these |
| [`assembly-views.scad`](assembly-views.scad) | the assembly pictures: exploded; open, with every wire's route and the wiring table; the wires at the pins close up; and the wires' collision check |
| [`feature-map.scad`](feature-map.scad) | the numbered feature pictures |
| [`fits-map.scad`](fits-map.scad) | the lettered picture of the clearance test |
| [`sps30-measure.scad`](sps30-measure.scad) | the two widths to measure on the SPS30 |
| [`board-measure.scad`](board-measure.scad) | the three readings taken on the SuperMini and the GY-SGP41 |
| [`docs/`](docs/) | the pages above and their pictures |

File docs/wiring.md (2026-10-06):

# Wiring

**Solder each wire into its pad's half-hole at the SuperMini's edge, with no headers.** Every wire comes
up to its pad from under the board, and every pad the node uses is at the board's USB-C end — so no wire
goes near the antenna. The sensors keep their own connectors, or in the SGP41's case its own pin holes,
so either can be swapped without unsoldering the SuperMini.

## Which wire goes where

The board's **front** edge faces the cover; its **back** edge lies against the back plate. Pins count
from the USB-C end.

| Wire | From | To the SuperMini | Its edge, as installed |
|---|---|---|---|
| SPS30 black | pin 1, VDD | **5V** | front, 1st |
| SPS30 orange | pin 5, GND | **GND** | front, 2nd |
| SPS30 yellow | pin 4, SEL | **GND** | front, 2nd |
| SGP41 GND | GND | **GND** | front, 2nd |
| SGP41 VIN | VIN | **3V3** — never 5V | front, 3rd |
| SPS30 red | pin 2, SDA | **GPIO5** | back, 1st |
| SGP41 SDA | SDA | **GPIO5** | back, 1st |
| SPS30 white | pin 3, SCL | **GPIO6** | back, 2nd |
| SGP41 SCL | SCL | **GPIO6** | back, 2nd |

The SPS30's colours are its own lead's, checked with a meter —
[`firmware/print-chamber.yaml`](../firmware/print-chamber.yaml) says how, why colours are not to be
trusted on another lead, and why the SGP41's VIN must be 3V3. Three wires share the GND pad: twist the
SPS30's orange and yellow together first.

## The routes

assembled, cover off, every wire drawn to its pin

At the board's USB-C end, from below and in front — the SGP41's four thick wires and the SPS30's five thin
ones, each meeting its pad:

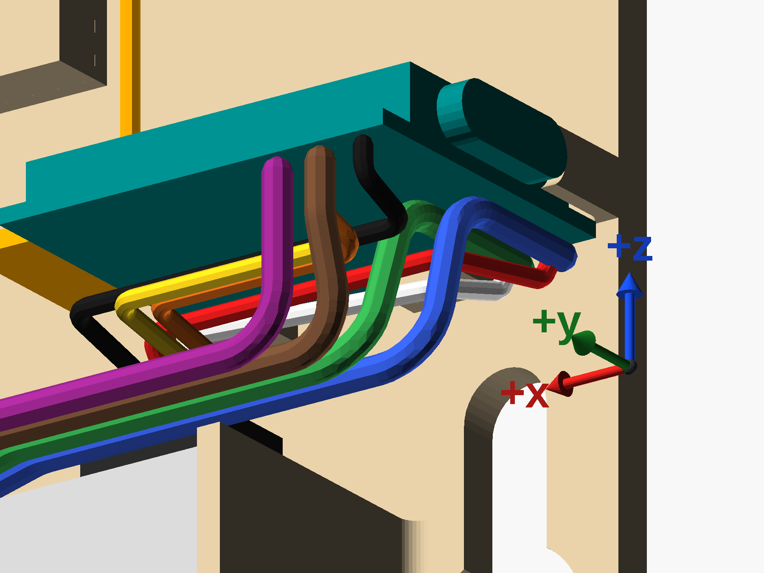
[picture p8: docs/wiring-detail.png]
the wires at the board's pins, from below


Both are drawn by [`assembly-views.scad`](../models/assembly-views.scad). The routes are one way the wires can
go — a wire bends where it likes — but each ends on its pin from the table, and the drawing checks them
(below). The SGP41's colours in the pictures are stand-ins: purple VIN, brown GND, blue SDA, green SCL.

**The SPS30's lead**

- It rises from its plug at the outlet end and bends over towards the board's USB-C end, inside the
  10 mm above the sensor its lead is given.
- **Orange and yellow**, for the front GND pad, run along the front at one height; **black** for 5V, and
  **red and white** for the back pads, run a wire higher — so each passes over the others' bends.
- Black, orange and yellow come straight up into the front pads from below.
- Red and white run behind the others, over the left wall screw's head, then under the SGP41's SDA and SCL
  to the same pads, and come up beside them at the end.
- **Shorten the lead** so it reaches the board with about a centimetre to spare, rather than coiling it.
  The SPS30 has a fan, and a slack lead buzzes.

**The SGP41's four wires** — 22 AWG solid

- **Solder them to come out of the module's back**, before it is screwed down: they leave towards the
  plate, then turn up, at least 1 mm from the board and round no tighter than about 3 mm.
- They rise behind the module, each above its own pin — VIN, the one nearest the SPS30, stepped a hair
  aside to clear the channel's wall — stepping to their lanes low down, below the right wall screw's
  head, then straight past it.
- Once level, they cross over the SPS30's top-left corner in **the wire channel** on the plate: press
  them in from the front past its lips, SDA nearest the plate and VIN outermost.
- Past the channel they **slant forward** — gently, so the slant does not bring them together — to cross
  the rest of the SPS30's top in front of its plug, about 3 mm above the sensor: under the lead's wires,
  and about 10 mm under the antenna.
- At the board's USB-C end, **SDA and SCL** climb to lie against the board's underside and run back to
  GPIO5 and GPIO6; **VIN** climbs straight up into 3V3; **GND**, which passes behind VIN, slants up into
  its pad beside it.
- The module's pins run SDA, SCL, GND, VIN from the side wall towards the SPS30; in the channel the
  wires lie SDA, SCL, GND, VIN from the plate outwards, and keep that order to the board, so no two
  cross.
- Cut each to length at its pad. Solid wire holds the shape it is bent to, so bend each to its route
  before soldering its second end.

**Under the back pads, two wires lie stacked**: the SGP41's against the board and the lead's under it.
That is why the keyholes sit `back_wire_room` (3 mm) below the board rather than just under its clips —
the wall screws' heads end up under those pads.

**Never** run a wire over the top of the board, near the antenna's loop or pole, or into the window or
the air gap in front of the SPS30.

## How much wire

Each wire's length is its route as drawn, bends and all. **Cut** adds 3 mm at each soldered end, for the
wire that goes through the hole and into the joint, and 10 mm to cut long by and trim at the pad; it is
rounded up to 5 mm. The SGP41's wires are soldered at both ends. The SPS30's lead is soldered only at the
pad — its other end is crimped into the plug — so for the lead, **cut** is how much of each wire to keep,
measured from the top of the plug: the lead shortened to reach with about a centimetre to spare.

| Wire | To | Route | Cut |
|---|---|---|---|
| SGP41 SDA | GPIO5 | 105 mm | 125 mm |
| SGP41 SCL | GPIO6 | 100 mm | 120 mm |
| SGP41 GND | GND | 87 mm | 105 mm |
| SGP41 VIN | 3V3 | 81 mm | 100 mm |
| SPS30 black | 5V | 33 mm | 50 mm |
| SPS30 red | GPIO5 | 32 mm | 45 mm |
| SPS30 white | GPIO6 | 24 mm | 40 mm |
| SPS30 yellow | GND | 27 mm | 40 mm |
| SPS30 orange | GND | 26 mm | 40 mm |

**The SGP41 takes 450 mm of 22 AWG solid wire in all**; half a metre covers it. The SPS30's lead comes
with the sensor, so only its length matters. A wire bent its own way rather than along the drawn route
will differ by a few millimetres — which is what the margin is for.

The open view prints these figures as it draws, as `wire length:` lines, and
`uv run scripts/checks.py lengths` checks this table against them, so a route that changes cannot leave
the table behind.

## Checking the routes

The `open` view checks the routes as it draws them, and stops with an `ERROR: Assertion` line if one
breaks — OpenSCAD still exits 0, so read the output:

- no bend tighter than its wire takes: 3 mm for the solid wire, 1 mm for the lead's;
- every wire clear of every other, except within 5 mm of a pad two of them share;
- every wire at least 3 mm from the antenna's loop and pole — they come to 4.1 mm;
- the two wires stacked under a back pad fit `back_wire_room`.

Its last line gives the tightest bend, the nearest two wires and the nearest the antenna.

The `check_wires` view intersects the wires with everything else in the box: both printed parts, the
SPS30 and its plug, the board, its parts and USB-C shell, the GY-SGP41, its screw's head, the wall
screws' heads as they slide up their keyholes, and the air gap in front of the sensor. Exported to STL it
must be empty, so OpenSCAD writes no file:

```sh
openscad -o check_wires.stl -D 'view="check_wires"' models/assembly-views.scad   # "Current top level object is empty"
```

It counts the strip along the GY-SGP41's pin holes, on its back, as bare — the wires leave the module
there. `uv run scripts/checks.py collisions` runs it with the box's collision checks, and
`checks.py controls` runs every row below (see [Checking it](checking.md)).

Each check has a setting that breaks it, measured 5 Oct 2026:

| Setting | What it breaks | Caught by |
|---|---|---|
| `gy_pitch = 1.0` | the SGP41's wires laid closer than they are thick | an assert: 0.68 mm of overlap |
| `bend_r = 6` | segments too short for the bends asked of them | an assert |
| `ant_clear = 5` | a limit the routes, at 4.1 mm, do not meet | an assert |
| `back_wire_room = 2.5` | less room under the back pads than the stacked wires need | an assert |
| `z_cross = 45.5` | the SGP41's wires lifted half a millimetre in their channel, into its roof rib | `check_wires`: 4.8 mm³, all in the channel |

The routes are laid out for the box as built, with the outlet at the right; the view refuses
`outlet_at_left = true`.

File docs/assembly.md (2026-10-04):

# Assembly

every part, moved apart along the way it goes in

## You need

- the two printed parts, from the fits found by [the clearance test](clearance-test.md);
- the ESP32-C3 SuperMini, the SPS30 with its lead, and the GY-SGP41;
- two **M3 × 20 socket head cap screws** and two **M3 nuts** for the cover;
- one **M2.5 × 6 socket head cap screw** for the SGP41;
- two **4 × 20 chipboard screws**, and their wall plugs, to hang it;
- **22 AWG solid hookup wire** for the SGP41's four wires;
- no tape and no glue: everything is held by the printed parts.

## Order

All of this happens before the cover goes on.

1. **Put the two nuts in.** Start each M3 nut square in its hex pocket from the back of the plate — the
   wall side. It seats 1.4 mm in, past where a thumb can push it: drive an M3 × 20 in from the other end
   of the boss and tighten until it draws the nut up to its shoulder, then take the screw out. The pocket
   is a press fit, so the nut stays.
2. **Set the SPS30 in from the front**, its lead plugged in, between its channel walls and onto its
   ledges, label towards you and air face down, back against its three ribs. Nothing on the plate
   overhangs it.
3. **Push the SuperMini's back edge into its clips** from the front, component side up and its antenna's
   pole standing up, until the edge snaps past the clips' catches. The back edge is the one whose first two
   pins are GPIO5 and GPIO6; its antenna end goes against the back stop.
4. **Screw the SGP41 on**, with its four wires already soldered into it from its back (see
   [Wiring](wiring.md)): lay it flat on its post and rib, sensor towards you and pins up, its bottom edge
   on its ledge, and drive the M2.5 × 6 through its mounting hole into the post's pilot. The first drive
   cuts the thread.
5. **Wire it** — see [Wiring](wiring.md).
6. **Put the cover on**, straight onto the plate: the USB-C socket slides along the slot in its
   right-hand wall until the plate's filler closes the slot behind it, the U at its top goes over the
   plate's bump, its front clasp takes the board's front edge, and its partition slides past the divider. Then drive the two
   M3 × 20 screws through its bottom corners into the nuts. Their heads end flush with the front.

The two "from the front" directions are not arbitrary. Each part's way in is checked against the back
plate in the model: the SuperMini's push into its clips, and the SPS30's path in. See
[Checking it](checking.md).

## Hanging it

On two screws, by the keyholes in the back plate — the way a wall clock hangs.

1. **Drive the two screws level, 55.3 mm apart**, where the box's bottom edge will be 46.8 mm below them.
2. **Leave each head standing about 3 mm off the wall** — between 2.4 and 3.4 mm. The plate is 2.4 mm
   thick, and the room behind it is 1 mm deeper than the head.
3. **Put both heads through the round openings, then let the box down.** The screws ride up the slots
   and the heads hold the plate against the wall. One screw may sit up to 2 mm lower than the other; its
   slot is that much longer.

The right-hand screw's steel head sits about 2 cm from the board's antenna. After hanging the box,
compare the node's Wi-Fi signal (RSSI) with what it reads on the bench.

**Clip the USB-C cable to the wall 3–5 cm from the plug**, on your right, with a stick-on cable clip. The
box has no cable clamp: a plug's body runs 2–3 cm out from the box's side before the cable starts, so
anything on the box would force the cable into a loop. The clip takes the cable's weight and pull off the
socket. The socket does not need one: its shell-sized opening takes side loads into the wall, and the
thinned wall takes a pull. More in [The USB-C end](usb-c-end.md).

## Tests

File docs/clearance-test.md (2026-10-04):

# The clearance test

**Every fit is tested now** — the last on 4 Oct 2026 — so the box needs no more of this. The test is
kept for when a setting, the printer or the filament changes: then reprint
[`air-quality-monitor-fits.scad`](../models/fits/air-quality-monitor-fits.scad) before the box, in the same ASA with the
same profile — one flat part, about 33 min and 3.2 g. It tries each fit three ways. Every piece is the box's own geometry — drawn by the box's own modules, with only the fit changed,
and lying on the bed as it does in the back plate — so it tests exactly what the box will print.

It holds the third round. The first two, printed 2 and 3 Oct 2026, settled every fit they tried but one —
their results are below — and their pieces are in the repository's history.

## Which piece is which

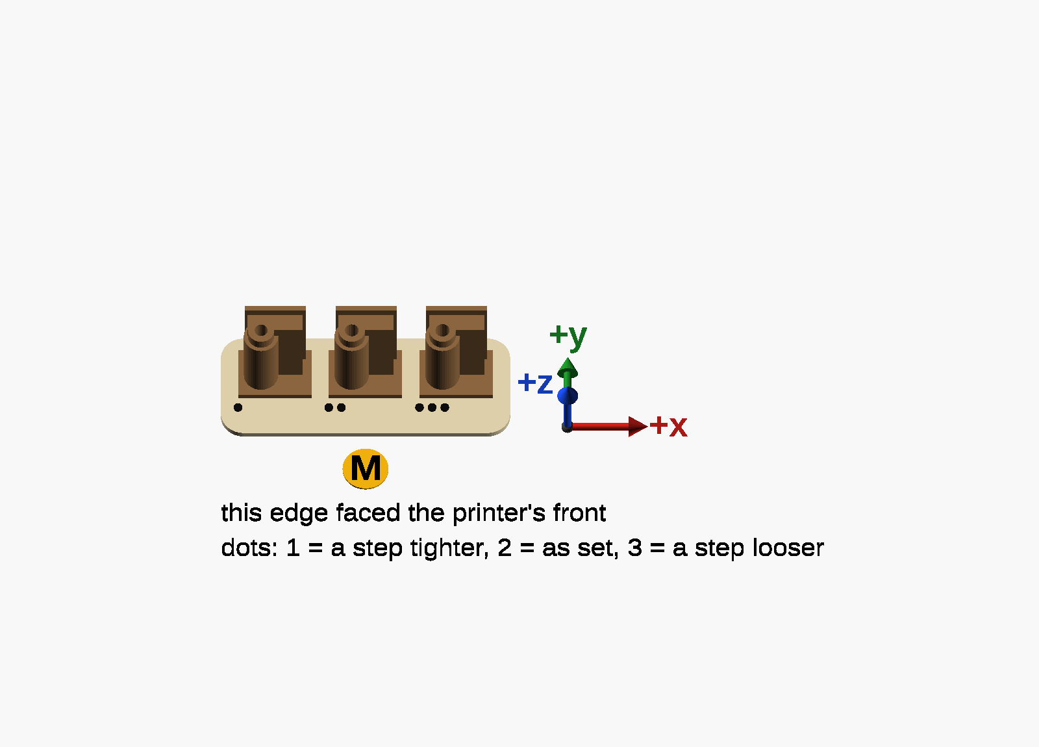
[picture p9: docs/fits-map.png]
the clearance test, lettered


Drawn by [`fits-map.scad`](../models/fits/fits-map.scad), which includes the test. Hold the part with the dots nearest
you — then it matches the picture, with the edge that faced the printer's front nearest you.

The arrows are the part's own axes, as it lay on the bed: **+x to the right, +y away from the front edge
(up the picture), +z up off the bed, towards you.** A reading given as "in x" or "in y" uses them.

Each try carries **1, 2 or 3 dots** in front of it: 1 = a step tighter, 2 = as set, 3 = a step looser. The
values below are for 1 / 2 / 3 dots. The letters go on from the earlier rounds' A–H and J–L, skipping I, so
that a letter always means one piece.

| | Pieces | Setting | 1 / 2 / 3 dots | Try | Pick |
|---|---|---|---|---|---|
| **M** | the three posts, each with its rib and ledge — the SGP41's mount | `gy_pilot_d` | 2.0 / 2.1 / 2.2 | lay the GY-SGP41 on each post, sensor up and its bottom edge on the ledge, and drive the M2.5 × 6 through its hole into the pilot, fully in, then back out — once per post, since the first drive cuts the thread | the one that bites firmly without splitting the post's 4.6 mm top or taking real force. No hole may go under 2 mm, so with the pilot at 2.0 a reprint tries 2.0 / 2.1 / 2.2 again: 1 dot is then the setting |

The keyholes the box hangs by are not tried here: they are sized from the wall screw with room to spare
— the slot 0.6 mm wider than the thread, at least 1 mm of plate under the head each side. The first
round's G confirms the thread's end of that.

The values follow the settings, so after a setting changes, a reprint tries a new ladder round it.

## Turning a result into a setting

Set the value in [`air-quality-monitor.params.scad`](../models/air-quality-monitor.params.scad) and delete its name
from `untested_fits`. If even the tighter try is loose, or the looser one still binds, the ladder was in
the wrong place: say so, and it moves.

## Results

**Third round**, printed 4 Oct 2026:

| Read | Group | Setting | Ladder | Pick | Now |
|---|---|---|---|---|---|
| 4 Oct 2026 | M | `gy_pilot_d` | 2.0 / 2.1 / 2.2 | 1 dot | **2.0** |

- **M** took the tightest try, which is also as small as a hole may go, so nothing tighter can be tried.
  It is the flat mount's post, upright, its top 4.6 mm across.

**Second round**, printed 3 Oct 2026. Its groups were: J, the M3 nuts' pockets; K, the SGP41's first
mount, on edge on a sideways standoff; L, pairs of the SuperMini's back clips.

| Read | Group | Setting | Ladder | Pick | Now |
|---|---|---|---|---|---|
| 3 Oct 2026 | J | `nut_fit` | −0.1 / 0 / 0.1 | 2 dots | **0** |
| 3 Oct 2026 | L | `clasp_pinch` | 0.2 / 0.1 / 0 | 2 dots | **0.1** |
| 3 Oct 2026 | K | `gy_pilot_d` | 2.0 / 2.1 / 2.2 | none: no standoff printed usably | untested |

- **J and L** each took the setting as it stood, so it stays.
- **K's standoffs did not print usably**, any of the three. Each is the box's own: a 4 mm peg standing
  2.7 mm out of its block, sideways, with nothing under it on the bed — the one real overhang in the
  back plate. It cannot be propped from below, because the module's own parts are there. The fault was
  the mount, not the pilot's size: the module now lies flat on a post, and the third round's M tries
  the pilot upright in it.

**First round**, all from the one print of 2 Oct 2026. Its groups were: A, the SPS30 frames; B and C,
trays for the two boards; D, bosses for the cover's self-tapping screws; E, upright pilots for the
SGP41's screw; F, the cover's screw holes; G, the mounting tabs' holes; H, a peg and socket.

| Read | Group | Setting | Ladder | Pick | Now |
|---|---|---|---|---|---|
| 2 Oct 2026 | A | `sps_fit` | 0.2 / 0.3 / 0.4 | 1 dot, snug | **0.2** |
| 2 Oct 2026 | B and C | `pocket_fit` | 0.2 / 0.3 / 0.4 | 1 dot for both boards, snug | **0.2** |
| 3 Oct 2026 | A, closer | `sps_fit` | 0.2 / 0.3 / 0.4 | 1 dot: flush in y, across the sensor's thickness; about 0.7 mm loose in x, along its width | **0.2** |
| 3 Oct 2026 | D | `pilot_d` | 2.3 / 2.5 / 2.7 | 2 dots fine; 1 dot a little tight, which may be better for a thread driven again each time the cover comes off. None split | **2.3** |
| 3 Oct 2026 | E | `gy_pilot_d` | 2.0 / 2.1 / 2.2 | 2 dots fine; 1 dot a little tight | **2.1** |
| 3 Oct 2026 | F | `screw_d` | 3.2 / 3.4 / 3.6 | 1 dot: an M3 passes freely | **3.2** |
| 3 Oct 2026 | H | `part_fit` | — | peg 5.98; socket 6.50 in y, 6.55 in x — 0.26 and 0.29 per side | **0.3** |
| 3 Oct 2026 | G | ~~`tab_hole_d`~~ | 3.8 / 4.0 / 4.2 | 3 dots fits the 4 × 20 wall screw | retired; the keyholes' slot is 4.9 as cut |

- **A, B, C, D and F** each took the tightest try, so nothing tighter has been tried.
- **A's x play was the width allowance, not the fit.** The frame's width was the datasheet's 41.2 mm
  across the sensor's side nubs plus the fit; flush in y said the fit itself was right. Measured on
  3 Oct 2026 instead: **41.00 across the nubs, 40.69 across the body**. The box's SPS30 channel now
  takes its width from those, so it is 0.2 mm narrower than the frame that was 0.7 mm loose:

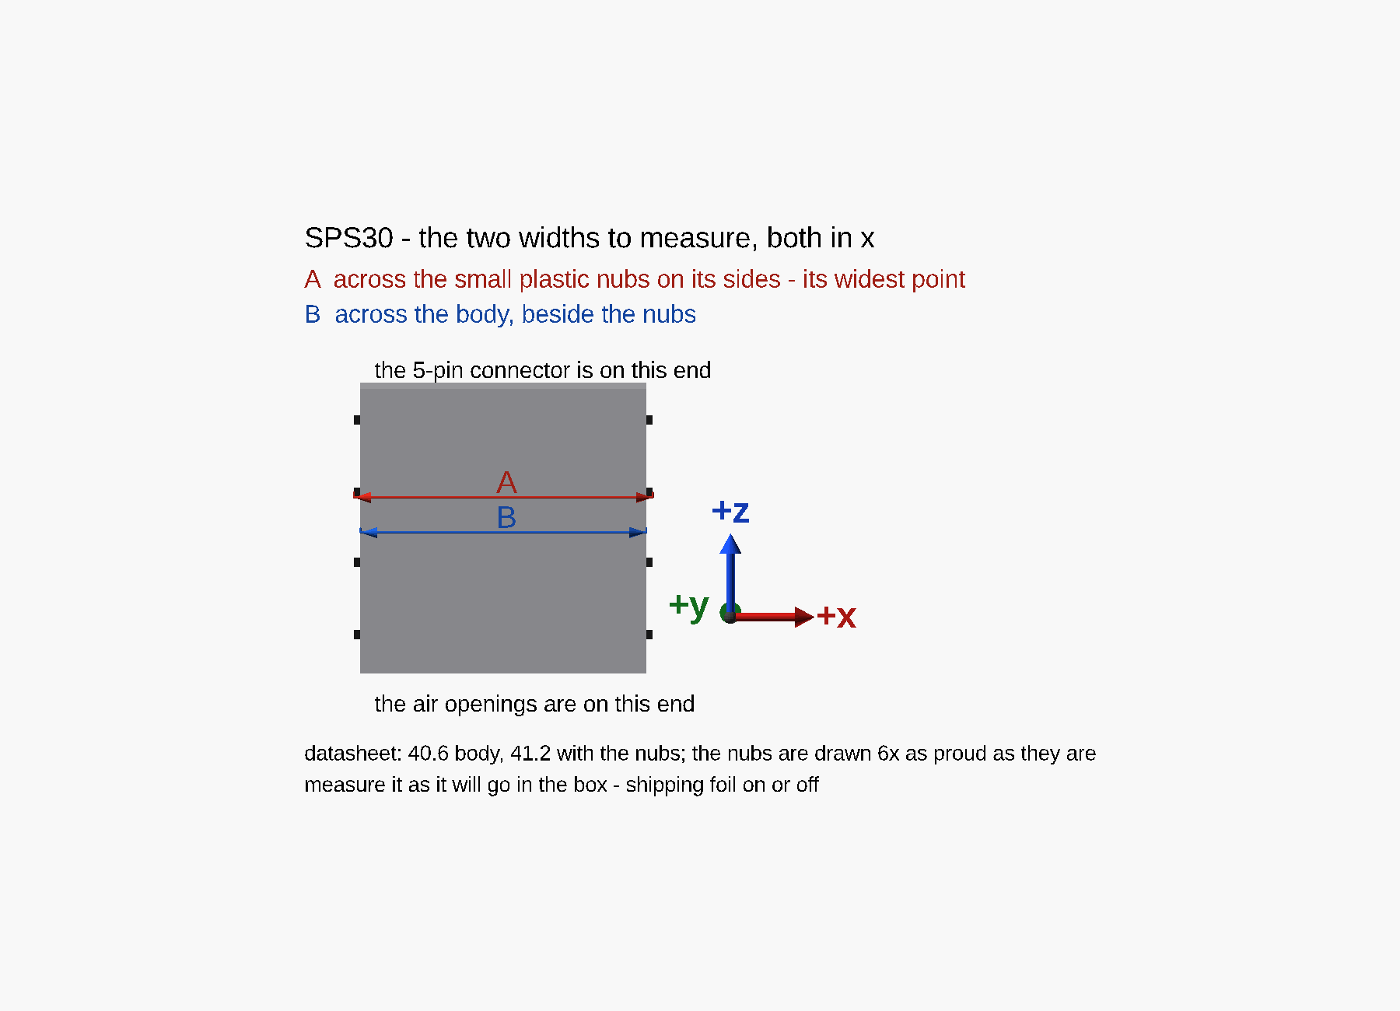
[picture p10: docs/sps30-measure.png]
the two widths to measure on the SPS30
  

  Drawn by [`sps30-measure.scad`](../models/fits/sps30-measure.scad), in the clearance test's axes.
- **D's screws stopped about 1 mm short in all three bosses**, because that print's pilots were 13 mm
  deep for a 14 mm screw. The three still compare. `pilot_d` has since gone from the box with the
  self-tapping cover screws: its bottom corners now screw into nuts.
- **E tried the SGP41's pilot upright, in a 6 mm boss.** The module stood on edge after that, with its
  screw sideways; it now lies flat with its pilot upright again, in a post only 4.6 mm across at its top,
  so the third round's M tries it there.
- **H**'s 0.26–0.29 mm is over the 0.15 mm floor, so `part_fit` stays at 0.3.

**G is retired**: on 3 Oct 2026 the box's mounting tabs, whose holes it tried, gave way to keyholes. It
was still read, with the wall screw that will hang the box: the 4.0 mm thread fits the 4.2 mm hole, so
the keyholes' 4.9 mm slot slides freely.

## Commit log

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2026-10-02 fix(models): print-chamber box - layout settled from photos of the parts
    Three photos of the parts settled what the placeholders had guessed.
    - The SPS30's outlet is on your RIGHT as you face the box, not the left:
    in the photo the two short inlet slits are on the left and the long
    outlet grille on the right, with the label up and the air face towards
    the camera, and tipping it so the air face points down keeps left and
    right. The connector is at the outlet end.
    - The SuperMini's underside reads 5 6 7 8 9 10 20 21 along one edge and
    5V G 3.3 4 3 2 1 0 along the other, both from the USB-C end. Every pin
    the node uses is at that end.
    - The antenna's straight wire stands out of the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
    [print-chamber-box-back.scad, print-chamber-box.params.scad, print-chamber-box.scad]
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2026-10-02 feat(models): print-chamber box - the parts measured
    Calipers on the parts in hand, 2 Oct 2026: SuperMini 22.8 x 18.03 mm, PCB
    0.85, 4.05 with its tallest part; USB-C shell 3.16 high and overhanging the
    PCB by 1.5; antenna tip 18.8 above the PCB's underside, loop 4.81 past its
    end; GY-SGP41 13.14 x 10.60 x 3.24.
    Three parameters now hold what was measured rather than what was asked:
    ant_h replaces wire_h (measured from the PCB's underside), and usb_shell_h
    replaces usb_center_h, which is now derived - the shell sits on the
    component side, since 0.85 + 3.16 = 4.01 against the 4.05 measured.
    The divider position comes from photo 3, scaled against the sensor's 40.6 mm
    width: the inlet slits,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
    [print-chamber-box.scad]
2026-10-02 fix(models): the measurements 979c59b describes but does not contain
    979c59b committed the model's half of the measurements without the params
    file's half. The step that builds the staged params file failed - a shell
    heredoc ate the backslashes in its Python - the chain did not stop, and
    git staged the copy left over from ddf78d7 instead. So at 979c59b the model
    asks for ant_h, usb_shell_h and the divider limits, the params file defines
    none of them, and the back plate does not render: exit 1, no STL, a run of
    "undefined operation" warnings.
    This commit carries that params file. The staging step is now a script
    file that deletes any stale copy first and checks what it staged, and the
    tree w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
    [print-chamber-box.params.scad]
2026-10-02 fix(models): print-chamber box - USB-C socket reaches the outside face
    The socket's mouth sat 0.6 mm inside the 1.8 mm wall, because the shell
    overhangs the PCB by only 1.5 mm. A plug's body therefore had to enter
    the wall, so the opening was sized for a measured plug. And whatever that
    measurement was, the back plate's edge (which the cover's opening does not
    reach) would have stopped a compliant 6.5 mm plug body 0.6 mm short of
    seating. Drawing that plug into f7cf397 gives a 6.1 mm3 overlap with the
    back plate.
    Now the wall over the board's end is thinned from inside to port_wall
    (0.9 mm, two beads), and the PCB reaches into that recess, so the mouth
    is flush to 0.6 mm proud. The opening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
    [print-chamber-box.params.scad, print-chamber-box.scad]
2026-10-02 feat(models): print-chamber box - the last measurements
    Measured 2 Oct 2026:
    - cable_zone_h 10 mm: the SPS30's lead plugged in and bent over. It
    equals the placeholder, and the SGP41's pocket still sets that zone's
    height (15 mm), so no geometry moves.
    - ant_loop_free 4.3 mm: the antenna loop leaves 4.3 mm of the board's
    end free on one side and 5.45 on the other. The smaller is used on both
    sides, so the box fits the board either way round. The loop dummy takes
    that width instead of a guessed 8 mm, and a new assert keeps the stops
    at the antenna end clear of it; they clear it by 1.6 mm.
    - gy_back 2.53 mm: the GY-SGP41 through its PCB and electronics, beside
    the sensor. Recorde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
    [print-chamber-box.params.scad, print-chamber-box.scad]
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2026-10-02 feat(models): print-chamber box - screw the SGP41 down by its hole
    Alon's call: the GY-SGP41 is held by an M2.5 x 8 socket head cap screw
    (ISO 4762, from the M2.5 box). The screw goes through the module's
    mounting hole into a blind 7.6 mm pilot in the ledge, and replaces the
    double-sided tape. The hole is in the bare strip, by the long edge away
    from the sensor. So the screw clamps only bare board, and its head clears
    the sensor. Which pocket edge that is follows from the way the pins face:
    photo 1, in both mirror states.
    The hole's size and position are read off photo 1 (2.7 across, centre
    2.7 from the far end and 3.4 from the nearer long edge). A pilot printed
    at a reading half a millimet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
    [print-chamber-box.params.scad, print-chamber-box.scad]
2026-10-02 fix(models): print-chamber box - hole rule covers the SGP41 pilot
    The 2 mm minimum-hole assert now includes gy_pilot_d. It passes at 2.1;
    gy_pilot_d 1.7, an M2's pilot, stops at it.
    The README stated that the screw head clears the sensor as fact. It is a
    photo reading (about 0.85 mm), and measuring the hole does not settle it,
    so it now says to check with the screw in the hole before printing. It
    also says that which pocket edge the hole sits by comes from photo 1, and
    that M2 is not the fallback for a smaller hole.
    [print-chamber-box.scad]
2026-10-02 feat(models): print-chamber box - the SGP41's hole, measured
    Measured 2 Oct 2026: the GY-SGP41's mounting hole is 3.13 mm. Its edge
    is 1.32 mm from the far end, the short edge opposite the pins, and
    1.25 mm from the long edge away from the sensor. The params file keeps
    the raw edge distances and adds half the diameter, so the centre sits at
    2.885 and 2.815; the photo had read 2.7 and 3.4. With the screw in the
    hole, its head sits clear of the sensor (checked by Alon).
    At the measured position, the pilot reaches 4.09 mm from the far end,
    past the 4.0 mm bare strip the ledge was sized to. The assert stopped it,
    as it should. gy_bare becomes 4.4. The measurement itself proves the
    board is bare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
    [print-chamber-box.params.scad]
2026-10-02 feat(models): print-chamber box - the clearance test
    One part that tries every untested fit three ways: a step tighter, as
    set, and a step looser, tagged with 1, 2 and 3 dots. It includes the
    box's params file, so every size comes from the settings it tests.
    - sps_fit: three open frames the SPS30 slides through
    - pocket_fit: three SuperMini trays and three GY-SGP41 trays
    - pilot_d / gy_pilot_d: bosses for the M3 x 14 and M2.5 x 8 screws, as
    deep as the box's
    - screw_d / tab_hole_d: a bar with both rows of holes, at the tab's
    thickness
    - part_fit: a peg and a socket, measured with calipers. A clearance
    between two separately printed parts cannot be tried within one part,
    and scad-che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
    [print-chamber-box-fits.scad]
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2026-10-02 docs(models): print-chamber box - numbered feature maps of both parts
    feature-map.scad draws each part with its features numbered. The back
    plate is seen as you face the box with the cover off. The cover is seen
    from inside, where most of its features are, so its left and right are
    swapped. The file includes the model, so every marker sits where the
    model currently puts that feature. The README's new section, "What each
    feature is for", shows both images and says what every number does.
    [feature-map.scad]
2026-10-02 fix(models): print-chamber box - SPS30 in from the front; SGP41 clear
    Three faults from Alon's review of the feature map, 2 Oct 2026.
    The SPS30 could not be fitted. Its channel's front lips overlapped its
    face, so it had to slide down from above. In that path stood the board's
    rims and stops, which sit above the channel wherever the board goes, and
    the SGP41's pedestal. The lips are gone, and the sensor is set in from
    the front. Once the cover is on, its partition rib, 0.3 mm off the
    sensor's face, keeps it from tipping. A new check, check_insert,
    intersects the back plate with the sensor's path in from the front. It
    is empty in both mirror states, and the design as pushed gives 131.8 mm3
    a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
    [feature-map.scad, print-chamber-box.params.scad, print-chamber-box.scad]
2026-10-02 fix(models): print-chamber box - the cable channel stands upright
    Alon: the channel should run up the picture, toward the pins. It ran
    sideways below the board, so the wires left its end by the side wall and
    had to double back to the pads. Now it stands upright, directly under the
    SuperMini's three power pins, from just above the SPS30 to just below the
    board. The wires press in from the front past its lips, run up it, and
    leave its top end straight into the 5V, GND and 3V3 pads.
    pin_mid (5.1 mm from the USB-C end, the middle of those three pins) is
    read off photo 1. The channel's room to the side wall and to the SPS30's
    lead is now a signed assert.
    Verified on the staged tree, OpenSCAD 20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
    [feature-map.scad, print-chamber-box.params.scad, print-chamber-box.scad]
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2026-10-02 feat(models): print-chamber box - exploded view and wire routes
    Alon: the channel is too long; make an exploded version with all the
    parts; route the wires.
    - The cable channel is now wire_ch_l (6 mm) long, measured down from just
    below the board, instead of the full drop from the SPS30. An assert
    keeps it at least as long as it is wide.
    - assembly-views.scad includes the model and draws two views:
    "exploded", with every part moved apart along the way it goes in (the
    SuperMini out to its USB-C side; the sensors, the screws and the cover
    out from the wall); and "wiring", assembled with the cover off and all
    nine wires routed to their pins, plus a close-up. The routes are
    illust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
    [assembly-views.scad, print-chamber-box.params.scad, print-chamber-box.scad]
2026-10-02 fix(models): print-chamber box - gentle SGP41 wire routes
    Alon, 2 Oct 2026: "the sgp41 wires may not be so forgiving". The route
    drawn in e0bd79a asked a lot of them. They left the module's pads with
    2.5 mm before the cover, bent flat, then dived about 14 mm back to the
    plate and turned up into the cable channel - three tight bends on short
    spans.
    The SGP41's four now leave the channel to the SPS30's five. They leave
    their pads straight towards the cover, bend over, and run straight
    across to the board in front of everything else: under the board until
    they are past its middle, then up to their pins and straight back in.
    The module's pins run SDA, SCL, GND, VIN, the reverse of the board's
    o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
    [assembly-views.scad, print-chamber-box.params.scad]
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2026-10-02 feat(models): print-chamber box - tested fits, 22 AWG solid wire
    The clearance test is printed. Alon, 2 Oct 2026: "sgp41, sps30 and c3
    are 1 dot". 1 dot is the step tighter, so sps_fit and pocket_fit go
    from 0.3 to 0.2 and leave untested_fits; five fits remain. That was the
    bottom of the ladder, so nothing tighter was tried. The box comes out
    62.6 x 88.53 mm, from 62.8 x 88.93.
    The wire: "solid wire thats owned". HomeBox has five 10 m coils of
    22 AWG solid, UL1007, whose outside diameter is typically 1.6 mm. The
    drawing now gives the SGP41's wires that diameter and a 3 mm bend, so
    wire_room goes from 5.0 to 7.0 mm behind the pin half (6.5 used). The
    SPS30's lead stays at 1 mm.
    The thicker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
    [assembly-views.scad, print-chamber-box.params.scad, print-chamber-box.scad]
2026-10-02 docs(models): print-chamber box - split the README into topic pages
    Alon, 2 Oct 2026: "make sure to keep docs updated and human readable.
    separate them into more clear topics. they may need a refactor."
    The README had grown to 480 lines in one file, mixing build steps,
    design reasoning, dated history and the checker's notes. It is now a
    one-page overview - what the box is, its status, the build order, the
    parts and hardware, how to print it - and the rest is in docs/, one
    topic a page:
    - to build it: clearance-test.md, assembly.md, wiring.md
    - to understand it: design.md, features.md, usb-c-end.md,
    sgp41-mount.md, parameters.md
    - to maintain it: checking.md
    Dated narration ("changed the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
    [assembly-views.scad, feature-map.scad]
2026-10-02 docs(models): print-chamber box - point the sources at the new pages
    The header comments of the model, the params file and the clearance
    test still sent readers to sections of README.md that moved into
    docs/ in 9a01341. They now name docs/design.md, docs/parameters.md,
    docs/checking.md and docs/clearance-test.md. No README pointer is left
    under models/print-chamber-box/.
    wiring.md said GPIO6's wire rises "half a pin" aside; since the SGP41
    moved to 22 AWG it is riser_aside, 1.4 mm.
    design.md's account of the back plate's seven bridge-infill regions
    re-traced on the current slice: Z 1.6 in the plate, 2.6 at the four
    bosses, 9.4 under the SGP41 pilot's floor (10.2) and 14.2 under the
    pedesta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
    [print-chamber-box-fits.scad, print-chamber-box.params.scad, print-chamber-box.scad]
2026-10-02 feat(models): print-chamber box - map of the clearance test
    Alon, 2 Oct 2026, on reading the rest of the clearance test: "show me
    which is which". fits-map.scad draws the test as it sat on the bed,
    seen from the printer's front and tilted 30 degrees, so the bosses'
    pilots and the socket show. Each group gets a letter, A to H. The base,
    the pieces standing on it and the dots are in three colours. It
    includes the test, so the letters follow the layout and the dots are
    the test's own. clearance-test.md now leads with the picture and a
    table keyed by the letters, with the value behind each dot count.
    The test called the M3 holes the bar's "upper row". Seen from the
    printer's front they are the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
    [assembly-views.scad, fits-map.scad, print-chamber-box-fits.scad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]
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2026-10-03 feat(models): print-chamber box - the bosses, holes and peg tested
    Alon read the rest of the 2 Oct clearance test on 3 Oct:
    - D, pilot_d (2.3 / 2.5 / 2.7): 2 dots fine, 1 dot a little tight,
    "which might be preferable"; none split. Set to 2.3, for a thread
    that is driven again each time the cover comes off.
    - E, gy_pilot_d (2.0 / 2.1 / 2.2): 2 dots fine, 1 a little tight.
    Stays 2.1.
    - F, screw_d (3.2 / 3.4 / 3.6): an M3 passes 1 dot freely. Set to 3.2.
    - H, part_fit: peg 5.98, socket 6.50 in y and 6.55 in x - 0.26 and
    0.29 per side, over the 0.15 floor. Stays 0.3.
    - A, looked at closer: flush in y, about 0.7 mm loose in x. sps_fit
    stays 0.2; the width allowance is the datasheet's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
    [print-chamber-box-fits.scad, print-chamber-box.params.scad]
2026-10-03 feat(models): xyz arrows on every figure
    Alon, 3 Oct 2026: "always add xyz arrows into the figures for better
    coordination". He reads the clearance test as it lay on the bed - up
    the picture +y, right +x, +z towards him - and a reading like "0.7 mm
    loose in x" needs both sides to share that frame.
    models/lib/axes.scad draws them: red +x, green +y, blue +z, each
    labelled at its tip, the labels turned to face the picture's camera.
    A label that lands on another arrow can be nudged, in label heights so
    the nudge holds at any size.
    All six print-chamber-box figures carry them, as the drawn model's own
    axes. For the box those are not the printer's: x across, y out from
    the wall, z up - so facing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
    [assembly-views.scad, feature-map.scad, fits-map.scad]
2026-10-03 docs(models): print-chamber box - what to measure on the SPS30
    Alon, 3 Oct 2026, on the request for the SPS30's width: "I don't
    understand what you want measured. Maybe make a figure."
    sps30-measure.scad draws it: the sensor's big face, straight on, with
    the connector end up and the air end down as it stands in the box, and
    two caliper readings in x - A across the small plastic nubs on its two
    plain sides, B across the body beside them. The clearance test found
    its frame A about 0.7 mm loose in x; these two readings replace the
    datasheet's 41.2 mm across the nubs, which that width comes from.
    Sizes come from the params file. Where the nubs sit is read off the
    datasheet's Figure 7, so it is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
    [sps30-measure.scad]
2026-10-03 feat(models): print-chamber box - the SPS30's width, measured
    Alon measured the sensor on 3 Oct 2026, as sps30-measure.png asks:
    41.00 mm across its side nubs (A) and 40.69 mm across the body (B).
    - sps_w 40.6 -> 40.69, the body.
    - sps_nub 0.3 -> 0.155 each side, (41.00 - 40.69) / 2.
    The datasheet's 41.2 across the nubs is what left the clearance test's
    frame A about 0.7 mm loose in x. The SPS30 channel is now 41.4 mm
    inside - the measured 41.00 plus sps_fit each side - and the box is
    0.2 mm narrower: the cover 62.4 mm, the back plate 90.4 mm with its
    tabs. sps_h, the other side of the big face, stays the datasheet's.
    Two positive controls measure differently with the narrower box and
    sti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
    [print-chamber-box.params.scad, sps30-measure.scad]
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2026-10-03 feat(models): print-chamber box - rebuilt round a level SuperMini
    The layout Alon settled on 3 Oct 2026, over four rounds of layout
    pictures:
    - "option B but 2 keyholes near the sps top corners. move the c3
    closer to the leads."
    - "use nuts for the bottom cover screws instead of screw on the top
    we should have poles that are rounded to slip into the screw holes.
    or a lip/latch on the cover that slips onto a groove on the top"
    What the model is now, 66.9 x 76.4 x 24 mm (was 62.4 x 98.3):
    - The SuperMini lies level on a shelf just over the SPS30's lead, its
    USB-C in the right-hand wall as before and its antenna's pole
    standing up. Its back edge goes under a short lip on the plate,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
    [assembly-views.scad, feature-map.scad, print-chamber-box.params.scad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]
2026-10-03 feat(models): print-chamber box - board in clips, cover top on a bump
    Alon, 3 Oct 2026, on the rebuilt layout:
    - "the shelf is too long +y have it pressfit into 7. make the lip a
    little bit longer +y and taperd so it will clasp the pcb without a
    lot of shelf. also this would allow more of the gpio pins to be
    accesible. it coulb also have a secound lip at the -X side of the
    pcb."
    - "the lip should angle in and out like a clip. it can be up to 2.1mm
    +Y"
    - "1 u shape that is from the top wall of the cover down -z. 1 bump
    where that u shape is hollow and touchs the back plate." - in place
    of the two pins.
    The SuperMini's shelf is gone. Its back edge pushes from the front
    into two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
    [assembly-views.scad, feature-map.scad, print-chamber-box.params.scad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]
2026-10-03 feat(models): print-chamber box - the wall screws, measured
    Alon, 3 Oct 2026: the box hangs on 4 x 20 chipboard screws - head 7.9
    across and 2.68 tall, thread 4.0. They replace the 3.5 mm placeholders,
    so the unmeasured list is empty. The keyholes' entry grows to 9.2 mm
    as cut and their slot to 4.9, leaving 1.5 mm of plate under the head
    each side; the columns beside the SPS30 widen to take the entry, and
    the box with them, to 68.7 mm.
    The 2 Oct clearance test's G row - retired with the mounting tabs -
    was still read with this screw: of 3.8, 4.0 and 4.2 mm holes it fits
    the 4.2, so the 4.9 slot slides freely. Recorded in the results.
    A chipboard screw's head is usually countersunk. The roo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
    [board-measure.scad, print-chamber-box.params.scad]
2026-10-03 fix(models): print-chamber box - the SGP41 the right way round
    The box held the GY-SGP41 mirrored. Photo 2 of 2 Oct 2026 shows the
    module from its sensor side with its pins up: the mounting hole at the
    bottom right, the sensor at the bottom left. The photo is not
    mirrored - the SuperMini's labels in the same picture read the right
    way round. Standing on edge with its sensor towards the side wall's
    vents and its pins up, seen from outside that wall, +Y is on the
    right, so the hole is by the module's FRONT long edge. The model had
    it by the plate: bottom left, the mirror image of any real module.
    gy_hole_right (true, from the photo) now records which way round the
    module is, and the hole's ed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
    [assembly-views.scad, print-chamber-box.params.scad, print-chamber-box.scad]
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2026-10-03 feat(models): print-chamber box - second clearance test, three fits
    The first round, printed 2 Oct 2026, settled every fit it tried, so a
    reprint of it would try nothing. The test now holds only the three
    fits still untested, each three ways - about 51 min and 6.4 g against
    1 h 45 min and 15 g:
    - J, nut_fit: the box's nut boss and hex pocket, open on the bed side
    as the back plate's are, so the first layer's squish narrows the
    pocket's mouth just as it will in the box. -0.1 / 0 / 0.1.
    - K, gy_pilot_d: the box's SGP41 block and standoff with its pilot
    sideways and as deep as the box's, backed by as much of the SPS30
    channel's wall as the box has behind it. 2.0 / 2.1 / 2.2.
    - L, clasp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
    [fits-map.scad, print-chamber-box-fits.scad, print-chamber-box.params.scad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]
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2026-10-03 feat(models): print-chamber box - SGP41 wires in a channel
    Alon, 3 Oct 2026: "add a small channel above the top left corner of
    sps30 for the wires from the sgp41".
    A short channel on the back plate over the SPS30's top-left corner,
    where the SGP41's four wires turn out of the module's column over the
    sensor: a slot between a floor rib and a roof rib standing on the
    plate, open to the front, gy_ch_len (8 mm) long. The wires lie side by
    side across its depth and press in from the front past a 45-degree lip
    on each rib, gy_ch_lip_gap (1.3 mm) apart - narrower than a wire, so
    each stays. The floor rib stands part_fit over the SPS30; the slot is a
    wire and 0.2 either side. The ribs print as wall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
    [assembly-views.scad, feature-map.scad, print-chamber-box.params.scad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]
2026-10-03 docs(models): print-chamber box - second clearance test read
    Alon, 3 Oct 2026, on the second clearance test (pcb-fits-r2, printed
    the same evening): "L=2 dot, J=2 dot, K didnt print corectly non where
    usable".
    - J, nut_fit: 2 dots, so 0 stays - tested.
    - L, clasp_pinch: 2 dots, so 0.1 stays - tested.
    - K, gy_pilot_d: none of the three standoffs printed usably. Each is
    the box's own: a 4 mm peg standing 2.7 mm out of its block, sideways,
    with nothing under it on the bed - the one real overhang in the back
    plate, which cannot be propped from below because the module's own
    parts are there. The fault is the mount, not the pilot's size.
    untested_fits is now gy_pilot_d alone; the README'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
    [print-chamber-box.params.scad]
2026-10-03 feat(models): print-chamber box - SGP41 flat behind the cover
    Alon, 3 Oct 2026, after the second clearance test's K - the SGP41's
    sideways standoff - printed unusably: "make the sgp41 flat and raisd up
    against the cover", then q34 "A", and q35: its board is 1.5 mm.
    The GY-SGP41 now lies flat in the left-hand column, its sensor 2.1 mm
    behind new vents in the cover's front and its pins up. One M2.5 x 6
    holds it from the front, through its mounting hole into a post rising
    from the plate. It lies on the post's top - 4.6 mm across, inside the
    bare ring round the hole - and on a rib under the bare strip along its
    bottom edge; its bottom edge sits on a ledge over the nut boss. Below
    the depth of i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
    [assembly-views.scad, feature-map.scad, fits-map.scad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]
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
